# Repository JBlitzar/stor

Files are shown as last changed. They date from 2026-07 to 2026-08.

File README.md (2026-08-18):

# stor

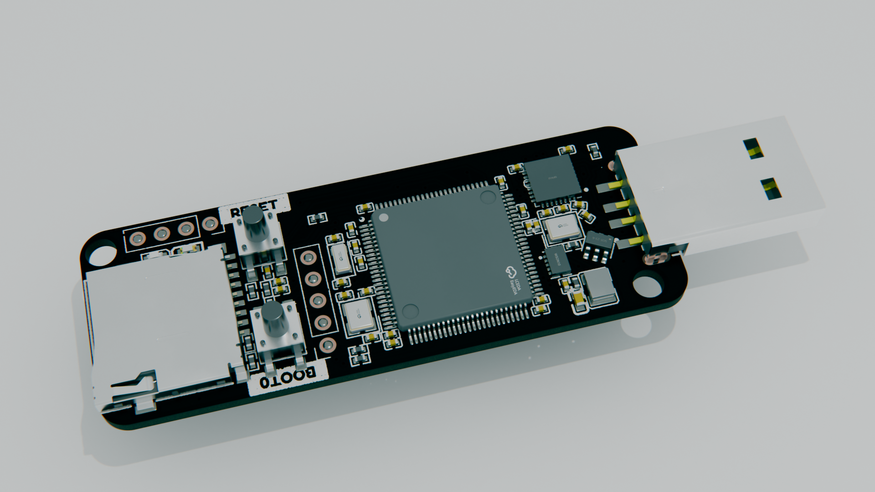
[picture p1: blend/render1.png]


A USB2.0 High Speed flash drive with a hotswappable MicroSD backend. 

The specs:

- USB 2.0 Hi-Speed
- STM32H723VGT6 MCU (Cortex-M7, 550 MHz class)
- MicroSDXC backend, up to 2 TB
- ~30–40 MB/s sustained, approximately saturating USB2.0

I made this because I always thought USB flash drives were pretty neat. So much storage! Easy file transfer! Ability to USB-boot! Making my own seemed like the perfect justification. Then, I saw that eMMC prices have in fact been inflated in accordance with the whole 2026 AI RAM shortage thing. You know what is still cheap per GB? microSD. You can absolutely get a respectable amount of storage (64gb, 128gb, 256gb) for just $10-20 if you source smartly. And microSDs have endless customization. They go up to 2TB. There exist industrially-rated ones with super high endurance. And, unlike BGA eMMC, they are hot-swappable.

The STM middleman is also fun because it means I can do all sorts of things, from custom USB descriptors to on-the-fly encryption or compression. The H7 even has crypto primitives, so it would be lightning fast! Implementation of this coming soon after the initial firmware is validated.

## Schematic

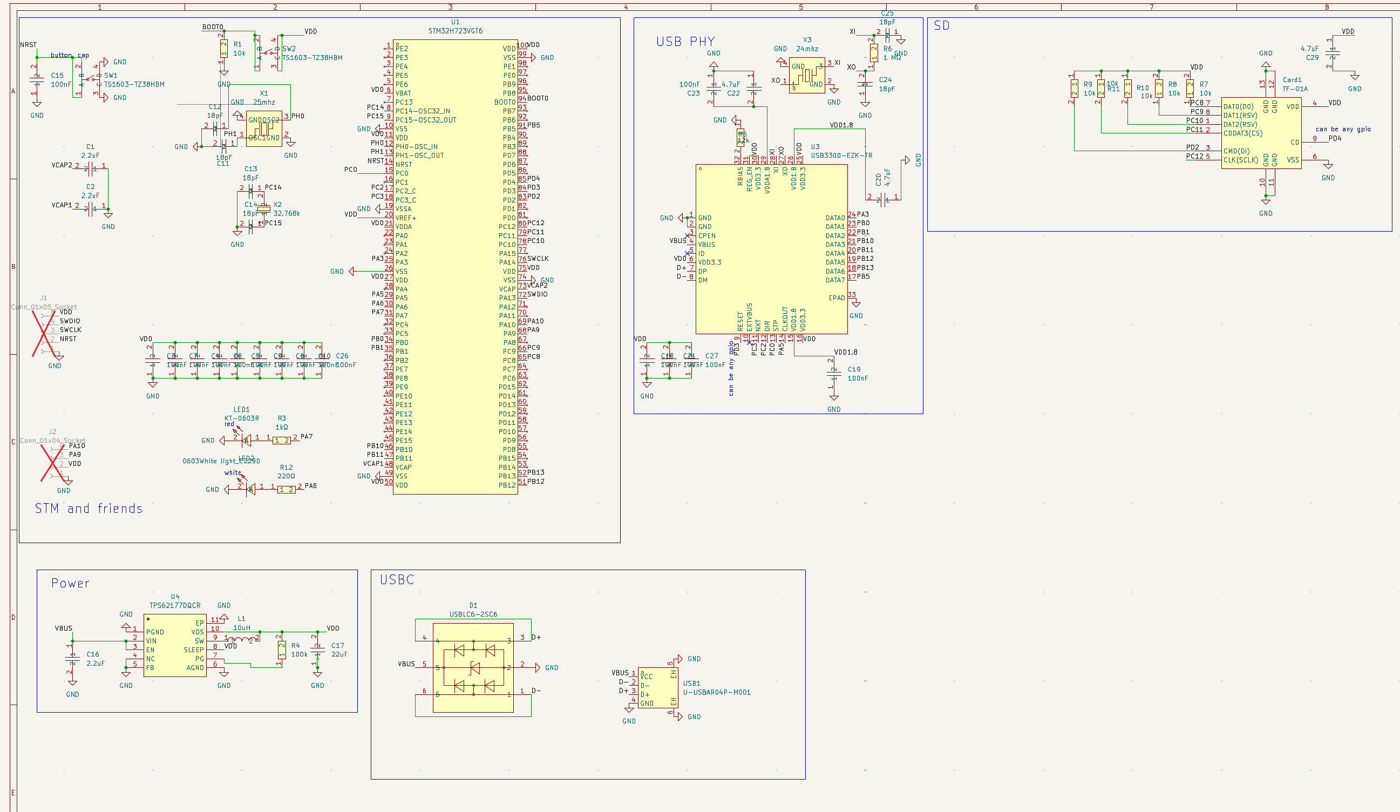
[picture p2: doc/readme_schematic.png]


## PCB

[Kicanvas](https://kicanvas.org/?repo=https%3A%2F%2Fgithub.com%2FJBlitzar%2Fstor%2Ftree%2Fmain%2FPCB%2Fstor)

F.cu and B.cu:

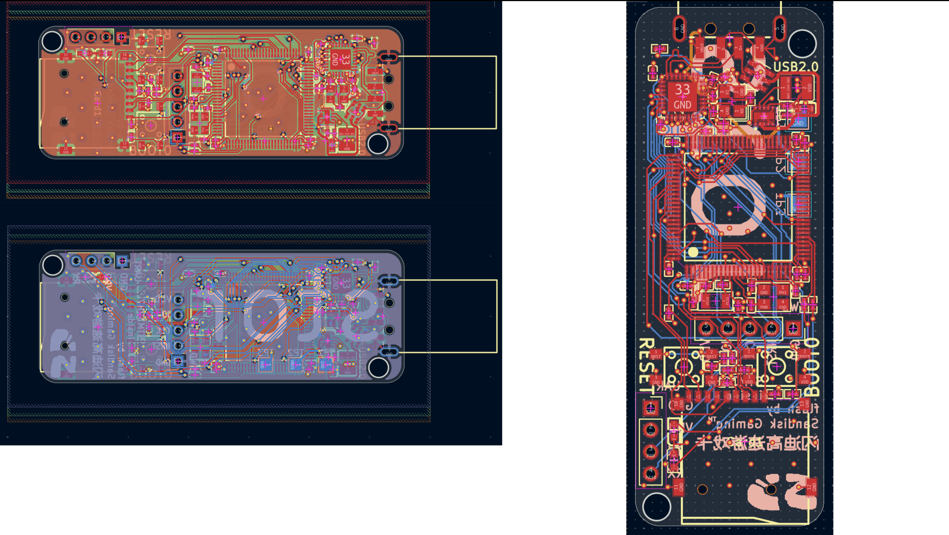
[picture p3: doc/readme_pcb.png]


## Usage

Standard USB to UART flashing configuration. Wiring diagram:

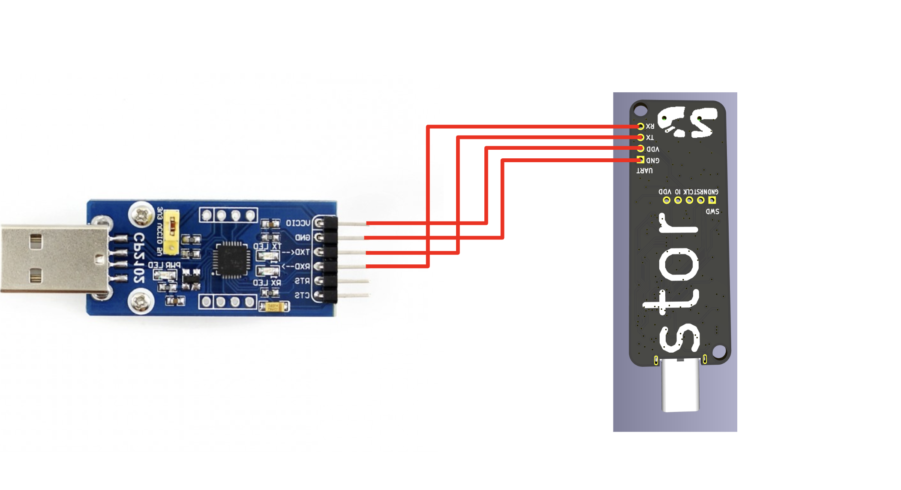
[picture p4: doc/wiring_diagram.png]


To flash the firmware:

1. `cd firmware`
2. Hold BOOT0, tap reset, release BOOT0
2. Run: `pio run -t upload`
3. Monitor: `pio device monitor`

It also might be possible to flash over USB. I haven't tested it though. Instructions are in [firmware/README.md](firmware/README.md), but in short:

1. `cd firmware`
2. `pio run` (to build)
3. Plug in the board, hold BOOT0, tap reset, release BOOT0
4. `dfu-util -a 0 -s 0x08000000:leave -D .pio/build/stor/firmware.bin`

I'll make this the default `pio run -t upload` behavior after it's been tested and verified.

Only plug in a microsd card after a successful first flash!

## CAD

Assembly STEP is at [cad/stor_assembly.step](cad/stor_assembly.step)

Case STEP is at [cad/stor_case.step](cad/stor_case.step)

Case is attached to the PCB through the circular pegs that go into the holes in the PCB

Onshape link: https://cad.onshape.com/documents/a7e5e47cc0cfc056916b5738/w/17c4e94553a6fc2d4495a917/e/2d8b03d1ea07a2cbf9c4bec4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

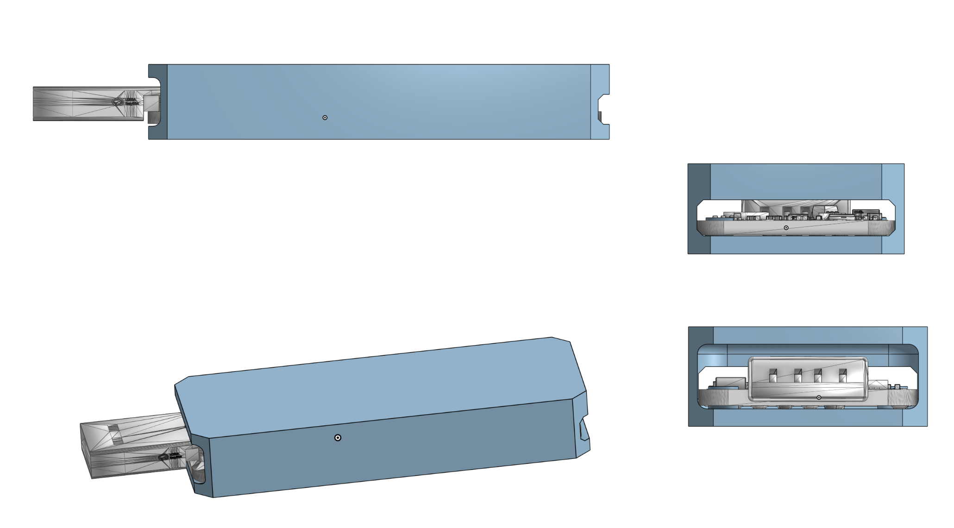
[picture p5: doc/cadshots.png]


## Credits

[TinyUSB](https://github.com/hathach/tinyusb) for the USB stack! LICENSE file is included in [firmware/lib/tinyusb](firmware/lib/tinyusb)

## BOM

|Item |Link |Cost |Notes |
|---|---|-----|---|
|CP2102 for flashing |http://waveshare.com/cp2102-usb-uart-board-type-a.htm|0 |Cost is zero because I'm flashing via FPGA. For others looking to reproduce, this is the simplest thing you can buy |
|SD card |https://www.lcsc.com/product-detail/C42416580.html |0 |I'll be paying out of pocket or self-sourcing. Feel free to gnab whatever listing you want, this is a 128gb listing for which I have no idea if it'll be reputable. Your safest bet is a sandisk off of amazon or digikey|
|PCB |N/A |7.1  |green pcb; other colors cost $5 more |
|PCBA |N/A |67.97|2x PCBA is the MOQ |
|JLC shipping + taxes|N/A |3.3  |Shipping special offer; may cost up to $8, but at the same time I have some coupons. So the total will work out about the same |
|Total |N/A |78.37| |
### Fabrication BOM

You'll find the rest of the fabrication outputs at [PCB/stor/production_real](PCB/stor/production_real)

|Designator |Footprint |Quantity|Value |LCSC Part #|
|---|---|---|---|---|
|C1, C16, C2 |C0402 |3 |2.2uF |C12530 |
|C10, C15, C18, C19, C21, C23, C26, C27, C3, C4, C5, C6, C7, C8, C9|C0402 |15 |100nF |C1525 |
|C11, C12, C13, C14, C24, C25|C0402 |6 |18pF |C1549 |
|C17 |C0603 |1 |22uF |C59461 |
|C20, C22, C29 |C0402 |3 |4.7uF |C23733 |
|CARD1 |TF-SMD_TF-01A |1 |TF-01A |C91145 |
|D1 |SOT-23-6_L2.9-W1.6-P0.95-LS2.8-BL |1 |USBLC6-2SC6 |C7519 |
|J1 |PinSocket_1x05_P2.54mm_Vertical |1 |Conn_01x05_Socket | |
|J2 |PinSocket_1x04_P2.54mm_Vertical |1 |Conn_01x04_Socket | |
|L1 |IND-SMD_L3.2-W2.5_CKST322512-2.2UH |1 |10uH |C39846661  |
|LED1 |LED-SMD_L1.6-W0.8-R-RD |1 |KT-0603R |C2286 |
|LED2 |LED0603-R-RD_WHITE |1 |0603White light_C2290 |C2290 |
|R1, R10, R11, R7, R8, R9|R0402 |6 |10k |C25744 |
|R12 |R0402 |1 |220Ω |C25091 |
|R3 |R0402 |1 |1kΩ |C11702 |
|R4 |R0402 |1 |100k |C25741 |
|R5 |R0402 |1 |12k |C25752 |
|R6 |R0402 |1 |1 MΩ |C26083 |
|SW1, SW2 |SW-SMD_4P-L4.5-W4.5-P3.00-LS6.8 |2 |TS1603-TZ38HBM |C36938886  |
|U1 |LQFP-100_L14.0-W14.0-P0.50-LS16.0-BL |1 |STM32H723VGT6 |C730142 |
|U3 |QFN-32_L5.0-W5.0-P0.50-BL-EP3.4 |1 |USB3300-EZK-TR |C108383 |
|U4 |WSON-10_L3.0-W2.0-P0.50-BL-EP |1 |TPS62177DQCR |C91241 |
|USB1 |USB-SMD_KH-USB-AM-4P-CB |1 |U-USBAR04P-M001 |C386752 |
|X1 |CRYSTAL-SMD_4P-L3.2-W2.5-BL |1 |25mhz |C9006 |
|X2 |OSC-SMD_L3.2-W1.5 |1 |32.768k |C97606 |
|X3 |CRYSTAL-SMD_4P-L3.2-W2.5-BL |1 |24mhz |C7420736 |

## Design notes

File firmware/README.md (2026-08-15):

# stor firmware

TinyUSB + ST HAL firmware. It's mostly boilerplate and plumbing.

## Build

```sh
pio run
```

## Flash

Either obtain a CP2102 dongle, or follow the instructions in [`fpga`](fpga/).

Hold BOOT0, tap reset, release
BOOT0, then:

```sh
pio run -t upload
```

### Flash over USB (untested)

Plug the board, then the
same BOOT0 sequence, then:

```sh
dfu-util -a 0 -s 0x08000000:leave -D .pio/build/stor/firmware.bin
```

This will probably work, but it's not tested. be prepared to potentially flash over uart/swd.

I'll make this the default `pio run -t upload` behavior after it's been tested and verified.

## Console

USART1 on PA9 (TX) / PA10 (RX), 115200 8N1, 3.3 V.

```sh
pio device monitor
```

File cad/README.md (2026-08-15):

Onshape link's at https://cad.onshape.com/documents/a7e5e47cc0cfc056916b5738/w/17c4e94553a6fc2d4495a917/e/2d8b03d1ea07a2cbf9c4bec4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

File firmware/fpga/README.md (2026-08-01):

# Icepi Zero FPGA flasher

This is how I'm going to personally flash since I want to avoid spending 16 dollars. 

You only need this if you happen to have an Icepi Zero lying around. For
everyone else, a CP2102 dongle is simpler.

## How it works

[`top.sv`](top.sv) is a pure combinational pass-through. esptool talks to the
Icepi's onboard FTDI exactly as it would to a CP2102; the FPGA just forwards
the data and modem-control lines (RTS->EN, DTR->boot) to four GPIOs:

| FTDI signal | FPGA pass-through | Hairtag pin |
|---|---|---|
| TXD (`usb_rx`) | `flash_txd` | TXD (ESP U0RXD) |
| RXD (`usb_tx`) | `flash_rxd` | RXD (ESP U0TXD) |
| RTS# (`usb_rtsn`)| `flash_en`  | EN (CHIP_EN) |
| DTR# (`usb_dtrn`)| `flash_dtr` | DTR (GPIO9 boot)|

## Wiring

The four signal GPIOs sit on the odd-numbered outer row, so VCC/GND/signals
are all reachable along one side of the 40-pin header:

| stor pin | Icepi 40-pin header | ECP5 site |
|---|---|---|
| VCC | pin 1 (VDD) | — (rail) |
| GND | pin 9 (GND) | — (rail) |
| TXD | pin 3  | T2 |
| RXD | pin 5  | R2 |



## Build and load

Requires the open-source ECP5 toolchain (`yosys`, `nextpnr-ecp5`, `ecppack`,
`openFPGALoader`).

```bash
make debug    # load to SRAM (lost on power cycle) - good for flashing sessions
make install  # write to flash (persists)
make clean
```

Once the bitstream is loaded, flash the normal way.

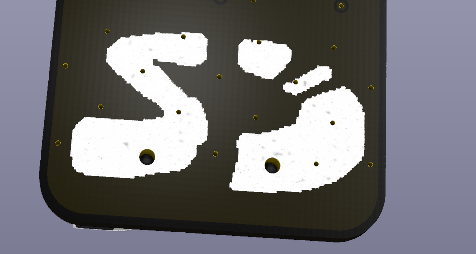
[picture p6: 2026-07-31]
doc/h.png

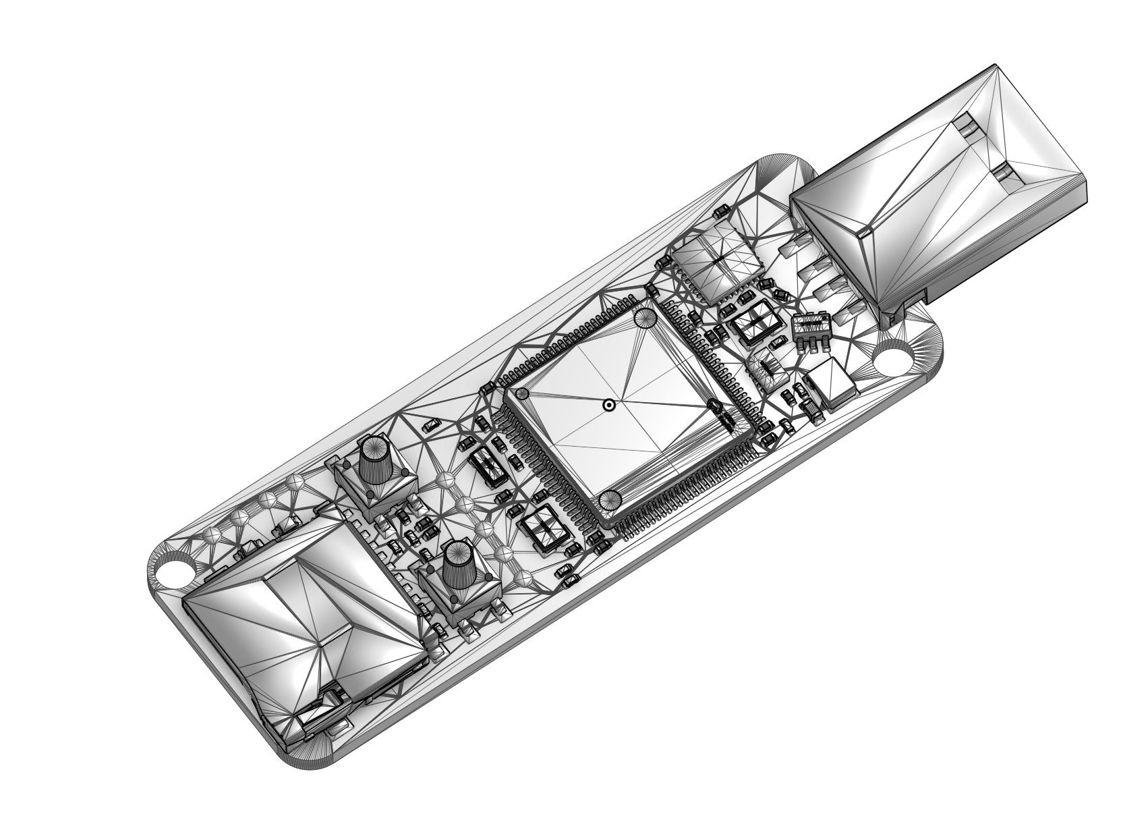
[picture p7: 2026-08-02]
doc/cadshot.png

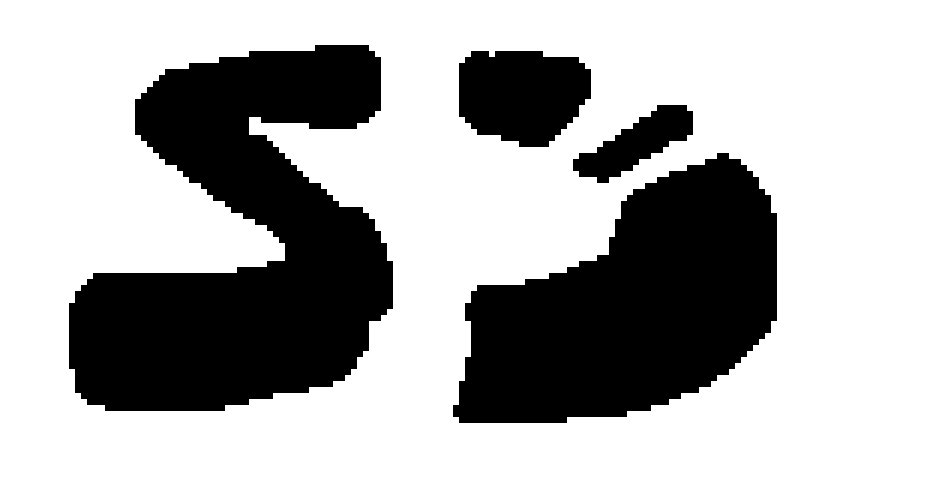
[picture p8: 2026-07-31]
doc/sd.png

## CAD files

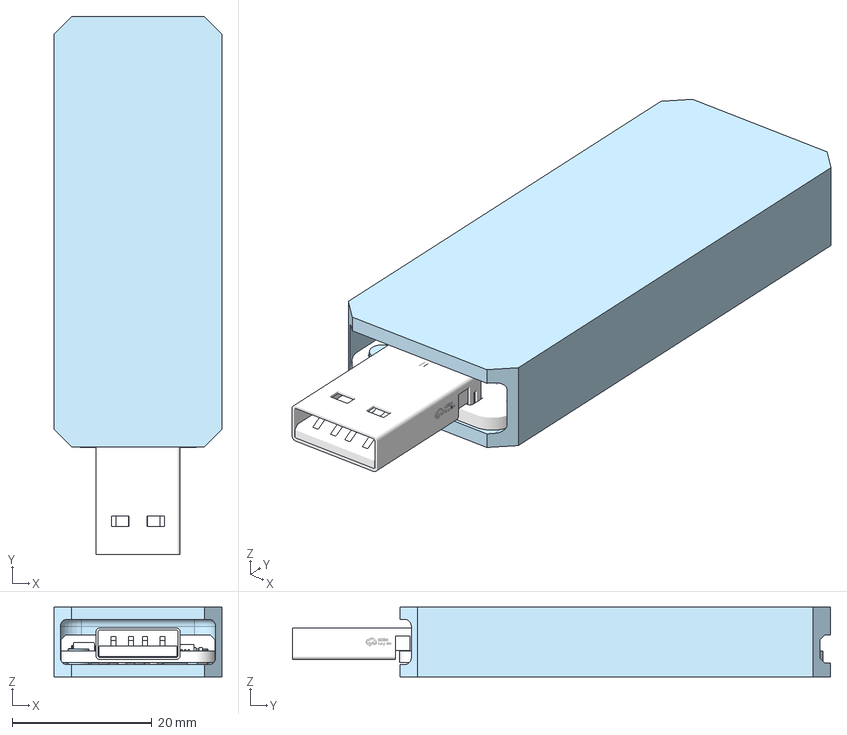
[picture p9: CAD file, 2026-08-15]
cad/stor_assembly.step
24.0 x 76.9 x 10.0 mm
SOLDER_25mhz_X1_35_3 x 8
SOLDER_4_7uF_C29_26_1 x 54
SOLDER_USB3300_EZK_TR_U3_52_7 x 16
SOLDER_STM32H723VGT6_U1_19_99 x 50
R0402_L1.0-W0.5-H0.4 (14) x 11
C0402_L1.0-W0.5-H0.5 x 27
SOLDER_STM32H723VGT6_U1_19_9 x 50
SOLDER_TS1603_TZ38HBM_SW2_39_3 x 8
SOLDER_TPS62177DQCR_U4_28_9 x 10
SOLDER_Conn_01x05_Socket_J1_33_4 x 7
QFN-32_L5.0-W5.0-H0.9-P0.50 (17)
SOT-23-6_L2.9-W1.6-H1.5-LS2.8-P0.95 (4)
SOLDER_USB3300_EZK_TR_U3_52_9 x 16
QFN-32_L5.0-W5.0-H0.9-P0.50 (15)
QFN-32_L5.0-W5.0-H0.9-P0.50 (7)
QFN-32_L5.0-W5.0-H0.9-P0.50 (6)
USB-SMD_KH-USB-AM-4P-CB
QFN-32_L5.0-W5.0-H0.9-P0.50 (32)
QFN-32_L5.0-W5.0-H0.9-P0.50 (3)
SOLDER_TF_01A_Card1_8_9 x 9
SOLDER_U_USBAR04P_M001_USB1_23_1 x 2
LED0603-R-RD_WHITE (1)
SOLDER_220?_R12_4_1 x 22
SOLDER_U_USBAR04P_M001_USB1_23_5 x 4
SOT-23-6_L2.9-W1.6-H1.5-LS2.8-P0.95 (6)
SOLDER_USBLC6_2SC6_D1_16_5 x 6
SOLDER_TF_01A_Card1_8_13 x 2
QFN-32_L5.0-W5.0-H0.9-P0.50 (29)
SOLDER_TPS62177DQCR_U4_28_10
SOLDER_TF_01A_Card1_8_14 x 2
SOLDER_KT_0603R_LED1_25_1 x 4
QFN-32_L5.0-W5.0-H0.9-P0.50 (24)
USB-SMD_KH-USB-AM-4P-CB (3)
USB-SMD_KH-USB-AM-4P-CB (8)
QFN-32_L5.0-W5.0-H0.9-P0.50 (11)
QFN-32_L5.0-W5.0-H0.9-P0.50 (9)
LED0603-R-RD_WHITE
LED0603_L1.6-W0.8-H0.6 (1)
QFN-32_L5.0-W5.0-H0.9-P0.50 (1)
QFN-32_L5.0-W5.0-H0.9-P0.50 (18)
SOLDER_32_768k_X2_5_1 x 2
LED0603_L1.6-W0.8-H0.6 (2)
QFN-32_L5.0-W5.0-H0.9-P0.50 (12)
QFN-32_L5.0-W5.0-H0.9-P0.50 (25)
LED0603-R-RD_WHITE (3)
QFN-32_L5.0-W5.0-H0.9-P0.50 (19)
QFN-32_L5.0-W5.0-H0.9-P0.50 (27)
LED0603_L1.6-W0.8-H0.6 (3)
SOT-23-6_L2.9-W1.6-H1.5-LS2.8-P0.95 (3)
SOT-23-6_L2.9-W1.6-H1.5-LS2.8-P0.95 (2)
SOLDER_22uF_C17_21_1 x 2
QFN-32_L5.0-W5.0-H0.9-P0.50 (26)
C0603_L1.6-W0.8-H0.8
QFN-32_L5.0-W5.0-H0.9-P0.50 (22)
QFN-32_L5.0-W5.0-H0.9-P0.50 (5)
QFN-32_L5.0-W5.0-H0.9-P0.50 (30)
QFN-32_L5.0-W5.0-H0.9-P0.50 (21)
CRYSTAL-SMD_4P-L3.2-W2.5-BL.001 x 2
USB-SMD_KH-USB-AM-4P-CB (7)
WSON-10_L3.0-W2.0-H0.8-P0.50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

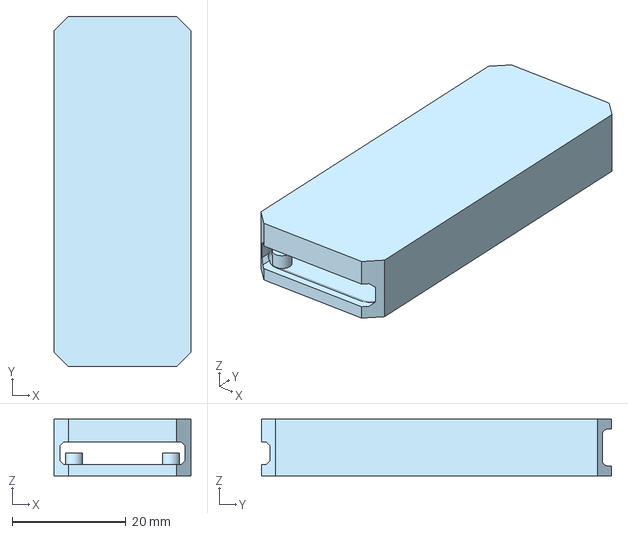
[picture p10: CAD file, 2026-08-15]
cad/stor_case.step
24.0 x 61.5 x 10.0 mm

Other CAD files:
blend/stor.blend

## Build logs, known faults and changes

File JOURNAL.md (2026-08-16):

---
title: "USB-C MicroSD Flash Drive"
author: "JBlitzar"
description: "High-speed USB-C microSD flash drive"
created_at: "2026-07-28"
---

# July 28: Developed the flash drive concept

Basically came up with the idea and assessed feasability. After thinking about my previous hardware projects, I thought a flash drive would be super cool. Why?

 - I love USB. Doing HS would still be USB but would be slightly levelled-up. usb3.0 in general like requires like NDA or FPGA or custom ASIC, so I thought I would go one step up instead of two for now.
 - I realized that eMMC is super expensive these days! shoutout to the [2025–present global memory supply shortage](https://en.wikipedia.org/wiki/2025%E2%80%93present_global_memory_supply_shortage)
, I guess. Sort of affects all memory-related ICs. It's not as bad as $80 for 2GB of LPDDR4 chip ram though. Still, decently expensive. I decided for this project I wanted to actually store files of a meaningful size.
 - The solution? [MicroSD cards](https://xkcd.com/691/)!! They have great data density (the highest-end ones can store up to 2TB these days), and are pretty cheap, especially if you source them off of the OEM supply chain like LCSC rather than consumer marketplaces like Amazon. I found a deal for 128GB for just $10 (??! probably trash data durability or a scam or both, but anyways I found plenty of other cheap listings that aren't too-good-to-be-true cheap). Plus, hotswappable storage is very hacker aesthetic. 
 - The good news is that USB3.0 isn't even worth chasing anymore, since we'll be able to saturate the SD card link speed itself. The link speeds actually don't bottleneck each other too much either way. With UHS-I enabled microSDs we're looking at 50 megabytes per second, and maybe 30-40 without. Pretty good.

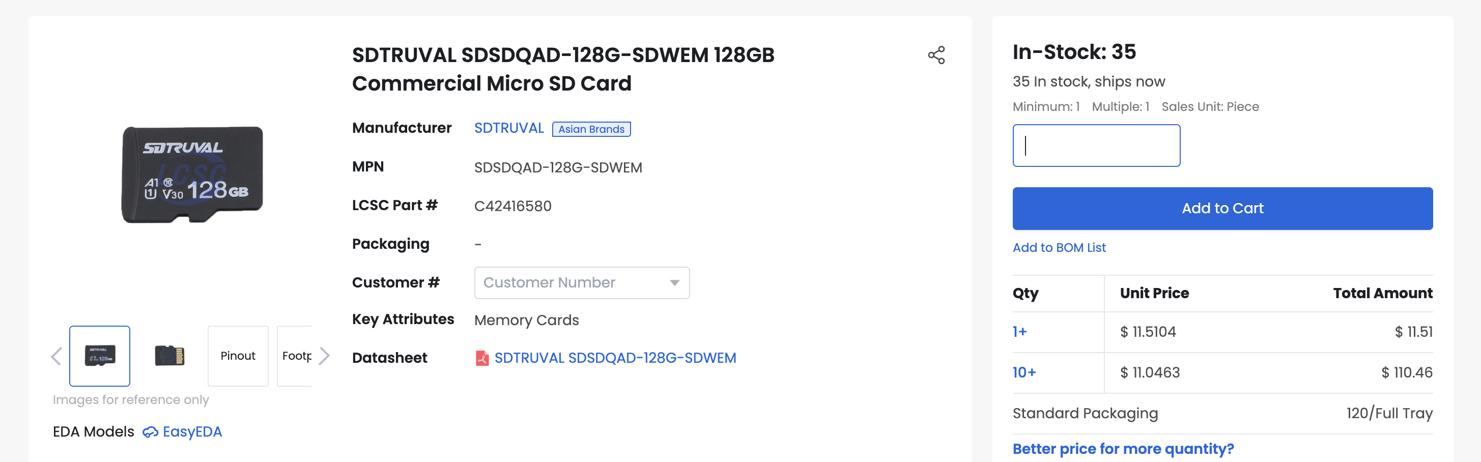
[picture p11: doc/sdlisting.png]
 

 yeah uh otherwise not much more to show, just research and concept

Time spent: 0.5 hours

# July 29: Selected the microcontroller and USB PHY

Did some research, locked in some more precise specs. 

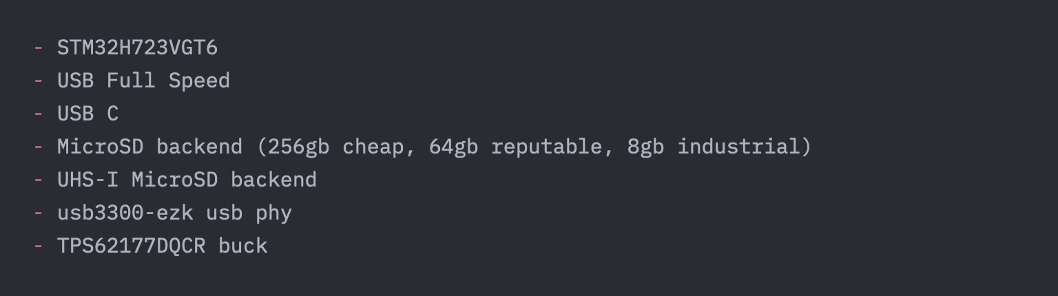
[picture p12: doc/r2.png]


Time spent: 0.5 hours

# July 29: Researched and completed the schematic

STM chip is the chip for the job. So unfortuantely I will have to depart from my goat espressif for this project. There do exist STM chips that have built in USB2.0 HS PHY, but they are more expensive (the lcsc listing I found was low stock AND $28 per, which is crazy considering the rk3566 costs just $14).

In the end, STM32H723VGT6 plus usb3300 usb phy is the way to go. The STM *does* have built-in sd card phy which is nice, and the clock speed is more than enough to saturate USB2.0 link speed. Later, I could do something cool, like on-the-fly encryption or something

Time elapsed taken from gh commit timestamps, I was working pretty much continuously.

Had to find actual resources. The STM datasheet wasn't too helpful, and the [DISCO schematic](st.com/resource/en/schematic_pack/mb1248-h747i-d03-schematic.pdf
) was... pretty intimidating, because it has examples for *every* peripheral. I went off of a [reddit post](https://www.reddit.com/r/PCB/comments/1n8w67u/stm32h723vet6_breakout_board_feedback_advice_for/
) for hardware/strapping, and hopefully I can just expose some GPIOs, flash over SWD, and pray.

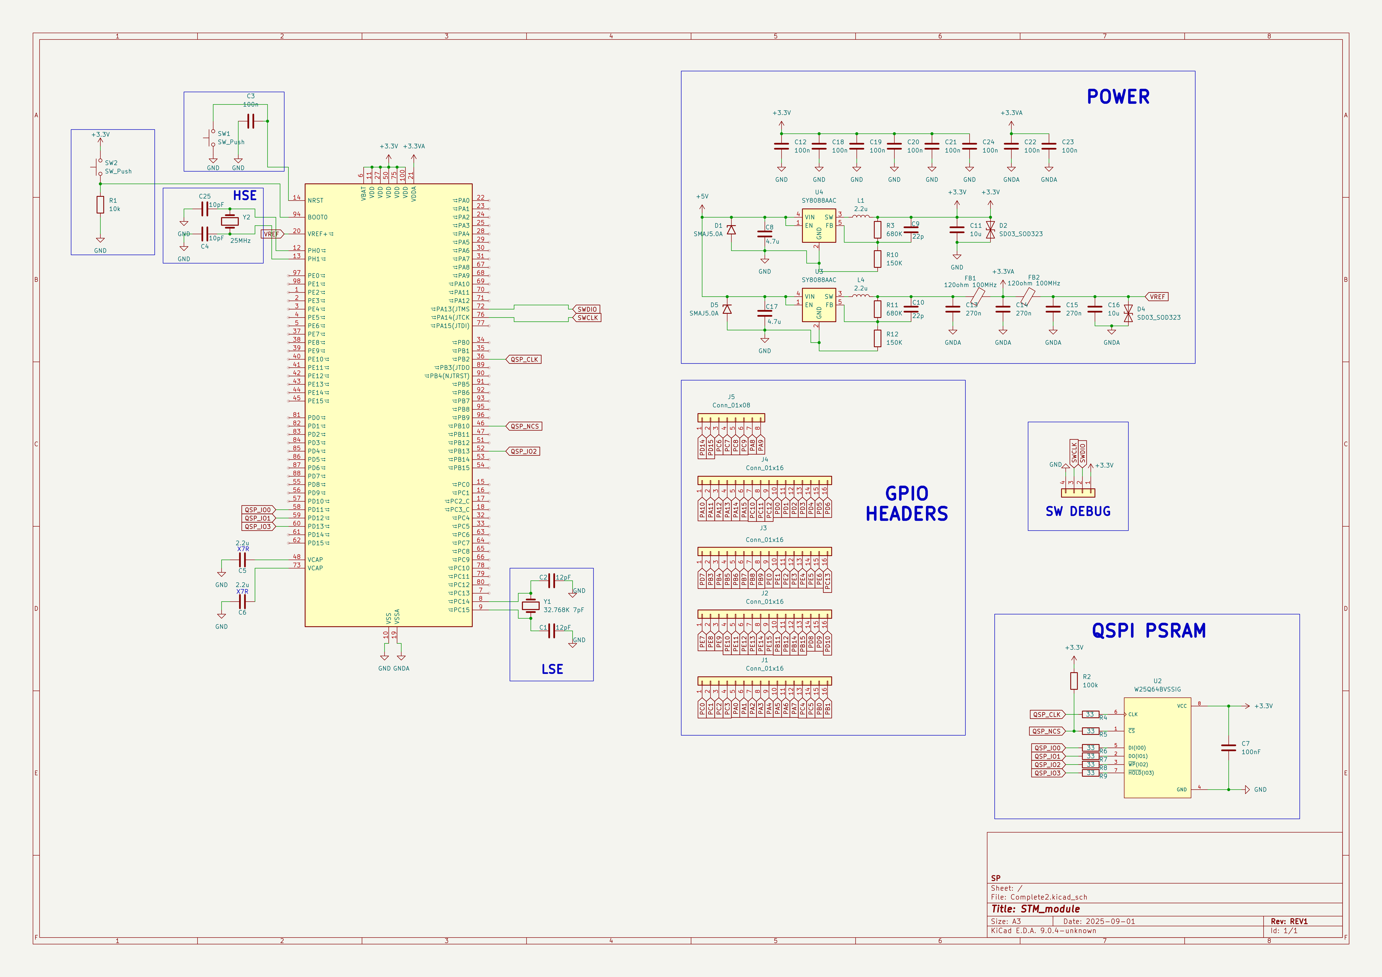
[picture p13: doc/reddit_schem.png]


Then I just researched which pins to connect up for the sd card and found a proper example schematic for the USB PHY (although they put ferrite beads everywhere which I omitted).

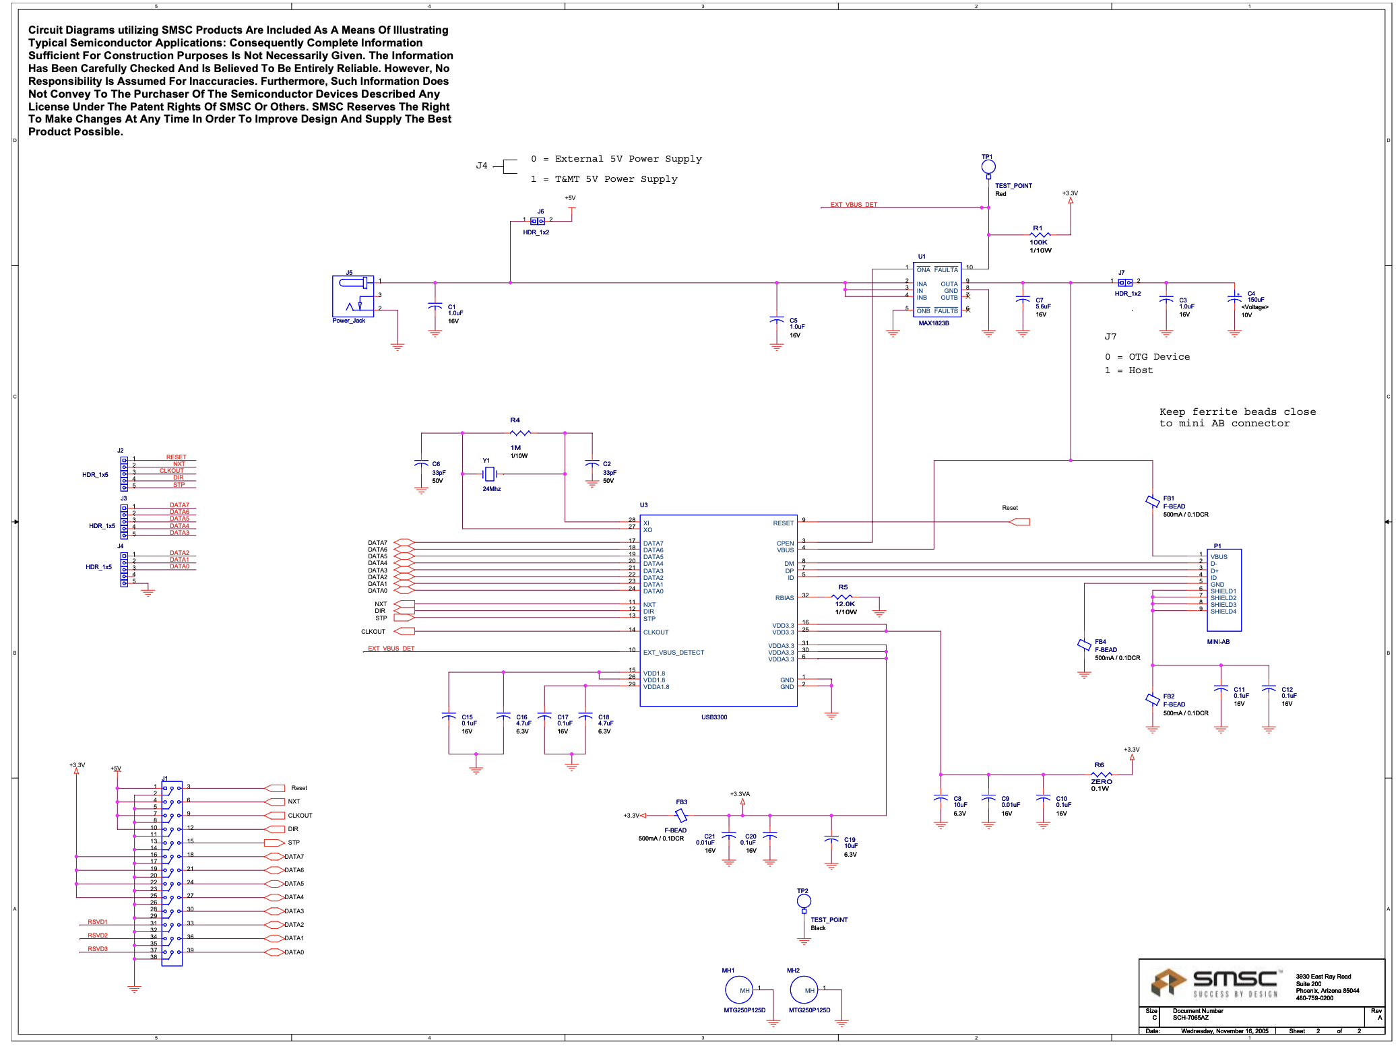
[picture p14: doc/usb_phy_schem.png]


TPS62177DQCR had a perfectly acceptable example schematic

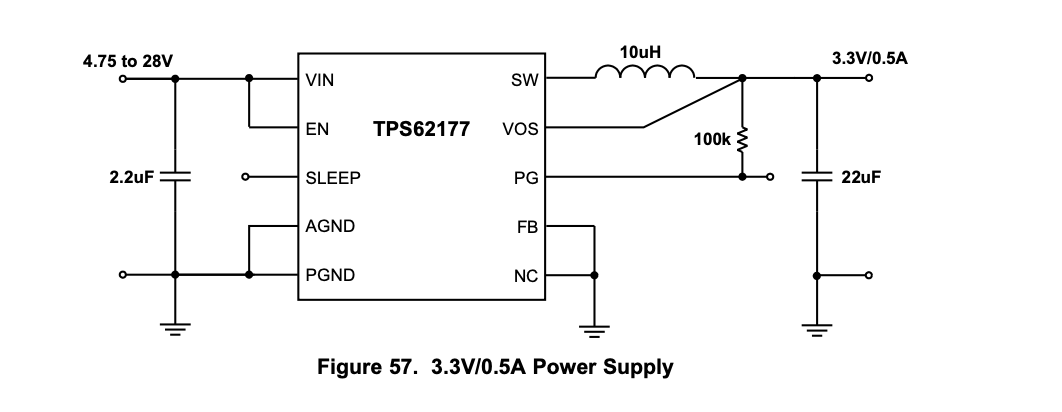
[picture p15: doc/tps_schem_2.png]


Then I put it all together! Had to use an A3 sheet because so big lol 

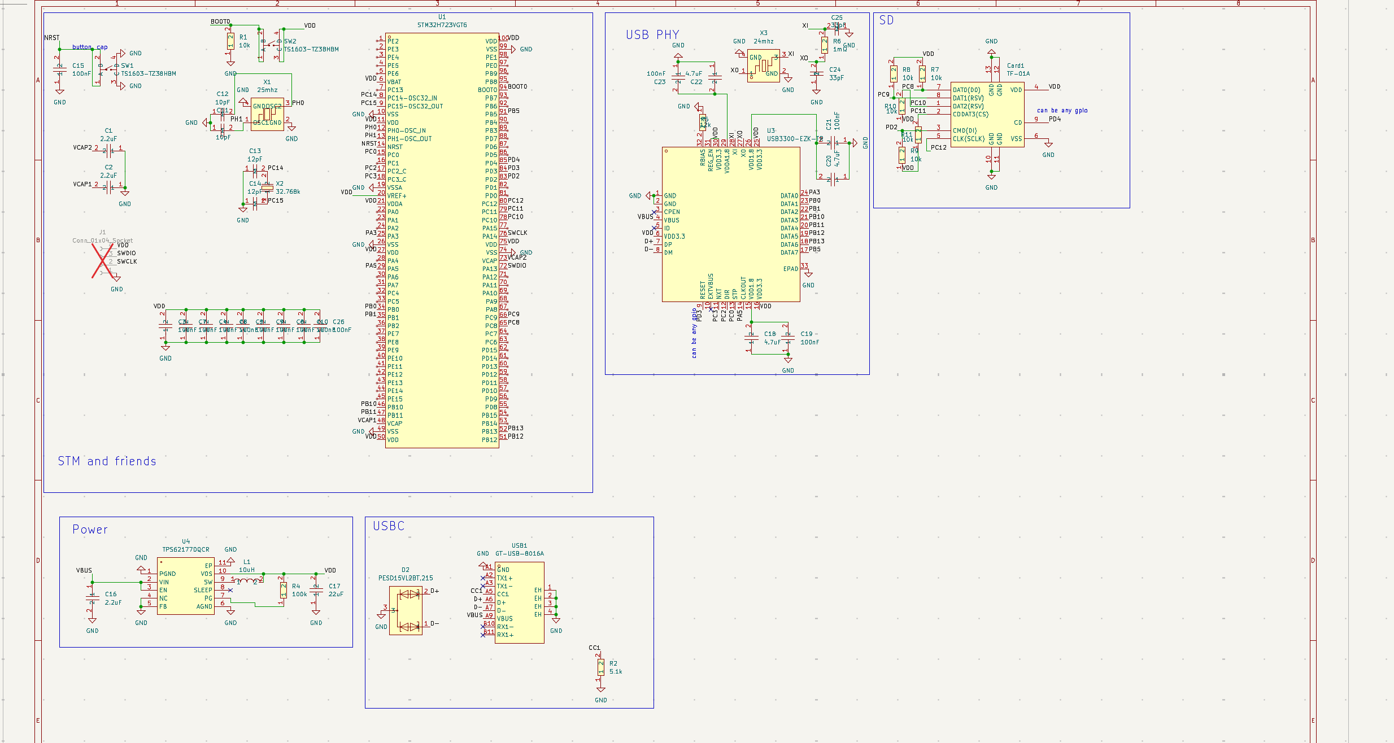
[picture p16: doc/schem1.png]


The STM pins were unfortunately not... charitably labelled. I used a lot of cmd+f.

Also some confusion between VDD/VDDA and GND/GNDA. Since I'm not doing any analog stuff, I merged them. Basically, the reddit PSU situation was way overengineered. That's why I went with the TPS.

So I guess research and schematic both took a surprising amount of time here.

Time spent: 4 hours

# July 29: Placed and routed the PCB

Placement and routing !!

You know what they say, good placement is 90% of good routing. What's cool is that I was pretty much able to fit everything in a standard thumb-drive footprint. Well, a slightly chunky thumb drive. Thumb drives are usually 18x60mm ish with casing, mine stands at 20mm wide without casing. Still acceptable. 

this is my first four-layer PCB, although honestly it feels like a two-layer pcb because I'm trying to keep the gnd and power planes solid, so there are really only two signal planes, just like normal. For the two most common traces though, gnd and vcc, all you have to do is via down and you tap the plane. GND plane important for usb2.0 diff pair, and four-layer esp important because it means the layers are thinner so impedance matching works out.

I'm not here to talk about impedance matching though, I just did placement. Here are some progress pics:

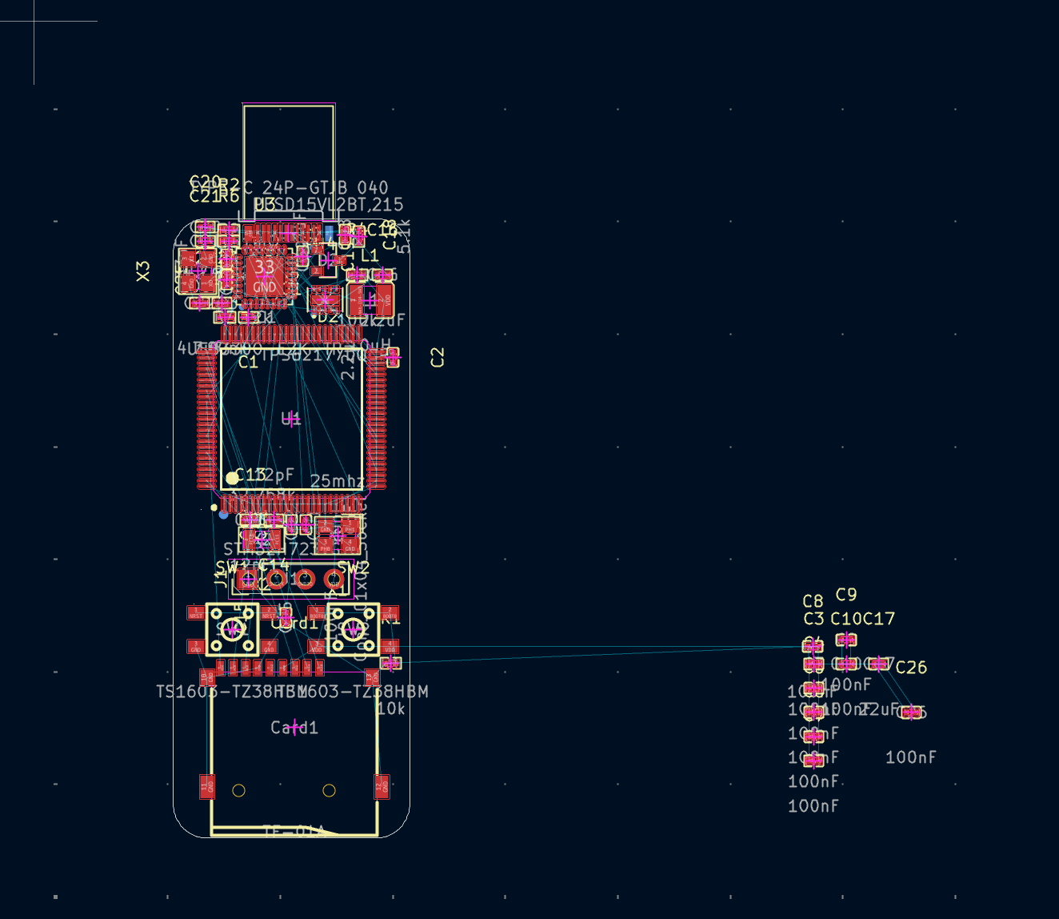
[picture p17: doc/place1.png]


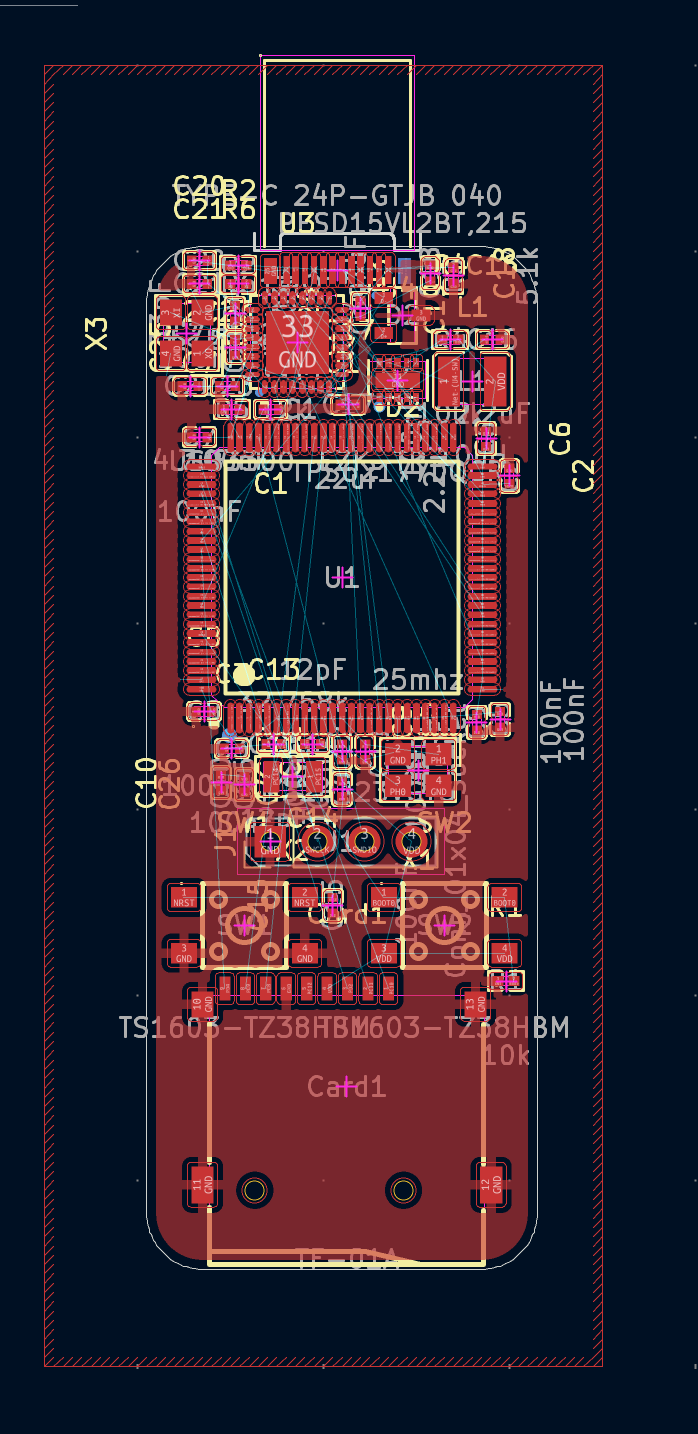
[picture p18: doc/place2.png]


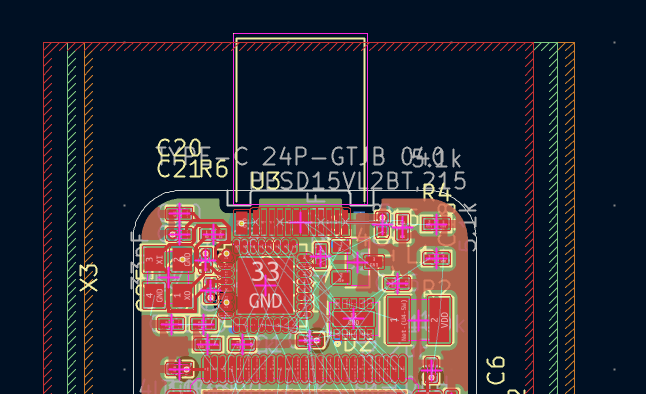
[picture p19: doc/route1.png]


Then I realized I had been putting off the differential pair when I really should have done it first. And really, my whole placement in that upper section was no good because of the rotation. I ended up completely refactoring the routing by changing the placement of the USB PHY ic. Which mean that the XO/XI caps plus the crystal had to all be re-placed.

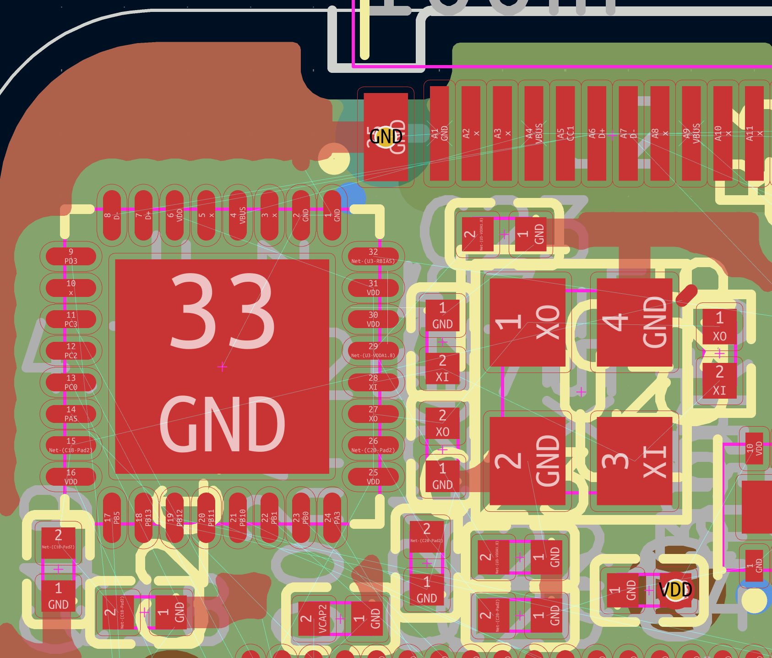
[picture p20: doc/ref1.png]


Then I just did the routing for the USB PHY and the sd card. Which is like sixteen bus lines, all interwoven.

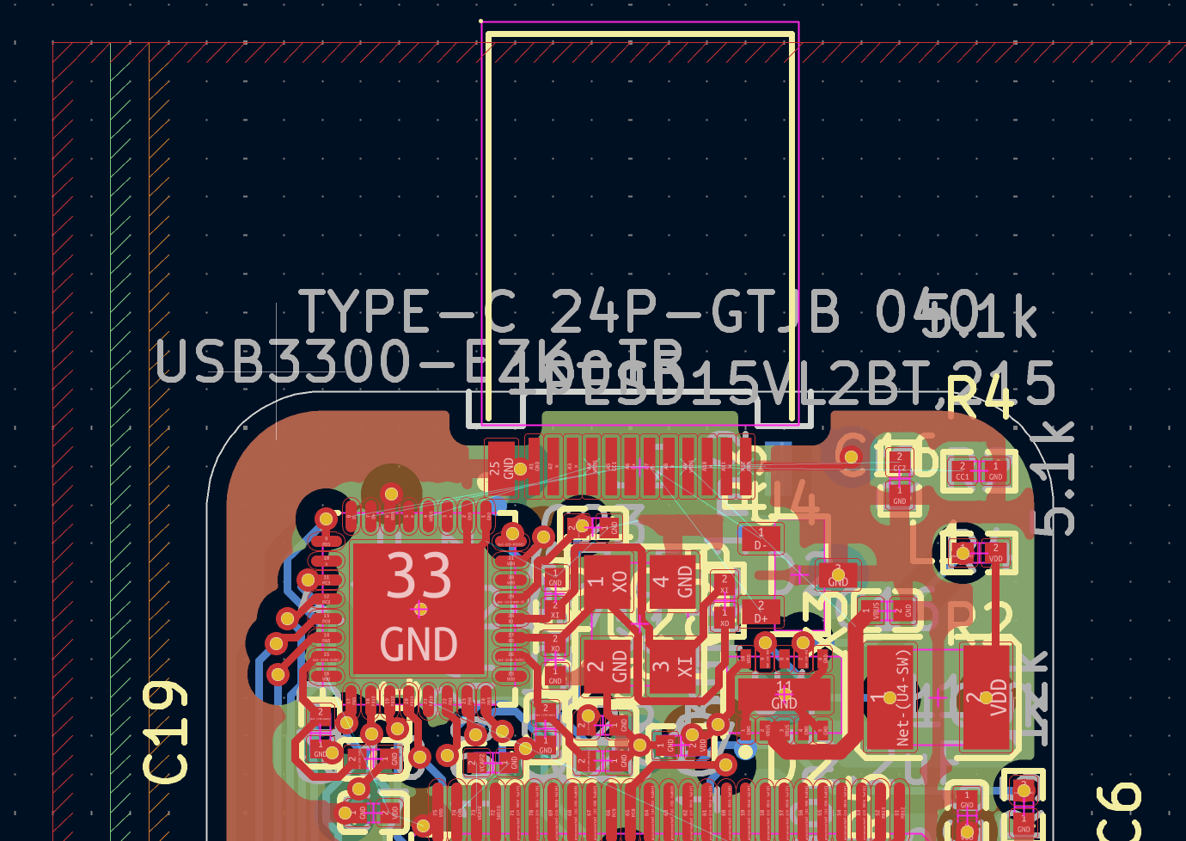
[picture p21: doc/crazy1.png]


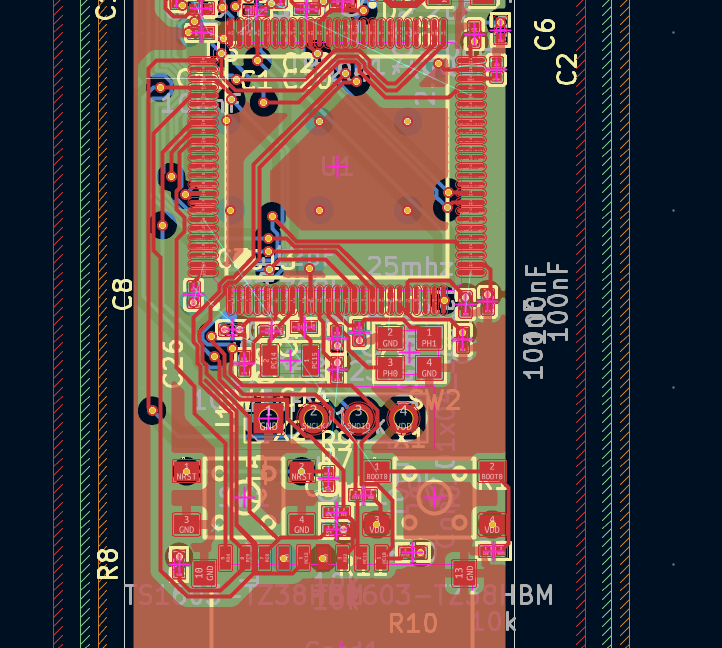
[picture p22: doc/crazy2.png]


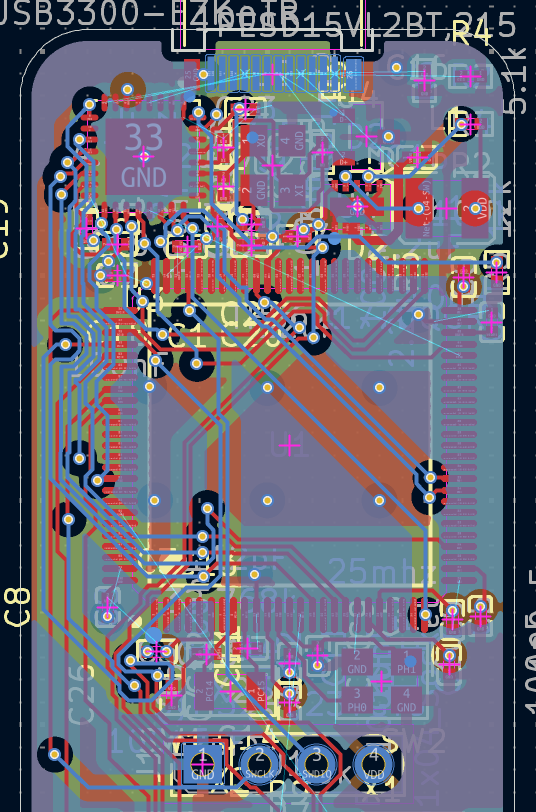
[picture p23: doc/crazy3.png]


Time spent: 2.5 hours

# July 30: Refined the routing and USB-C connector

Fussed with the routing a little bit. Managed to get some of the SD bus traces slightly further from the edge, which is probably good for case considerations even if solder mask exists. push and shove routing really is my goat. EasyEDA could never compete. (speaking of which, the newest kicad nightly update releases constraint-driven geometry! so cool! But I digress.)

Yeah, the routing looks quite... intricate ATP

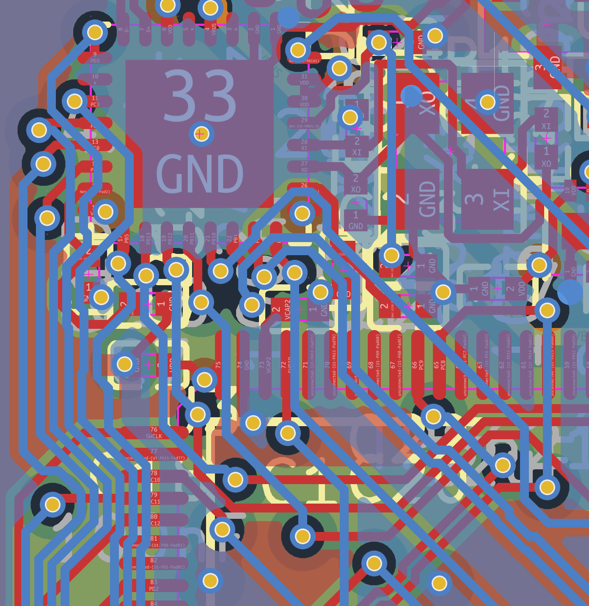
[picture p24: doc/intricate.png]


I also swapped out my THT USBC male for a different one that's less sketch and not weird and double-sided. This one will be more secure. It also had the escape routing I needed for the D+ and D- diff pairs to line up on the right side. 

Time spent: 1.0 hours

# July 31: Documented the design and added mounting holes

I realized that I hadn't been writing journals, so I wrote journals.

oh also I realized I haven't shown a 3d render, here it is!

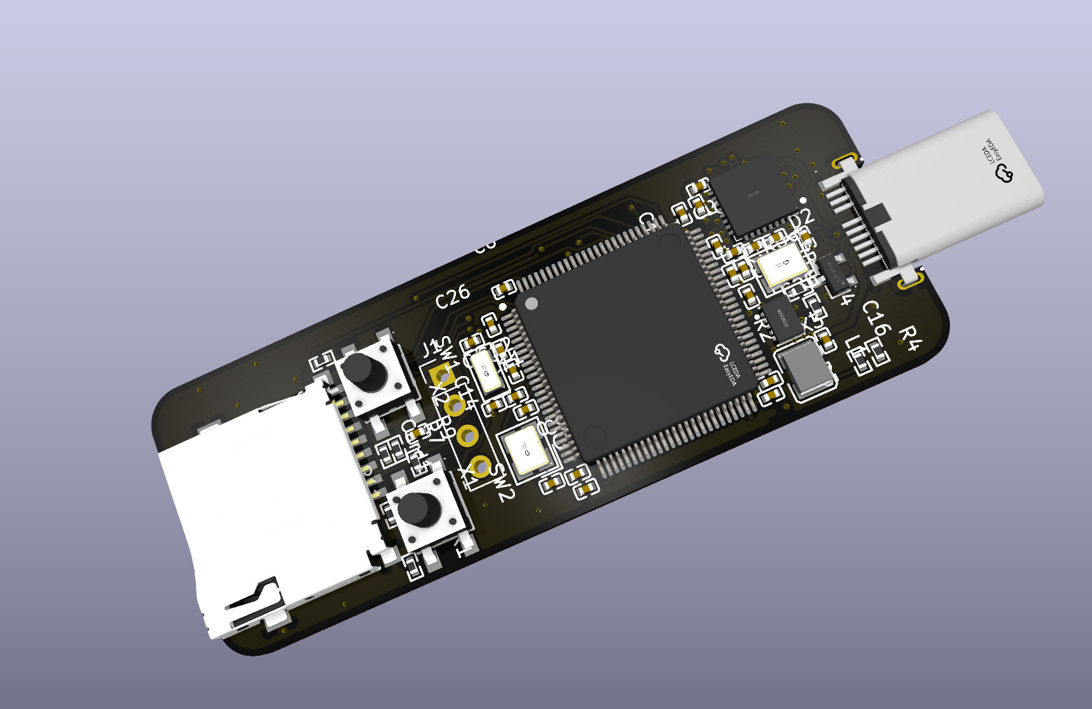
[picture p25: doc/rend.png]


The front is pretty packed with components. I think it looks cool.

I also uh drew my own SD logo in jspaint because I thought it'd be funny. I didn't pay the $1500 SD™ licensing fee. Front was pretty busy though so I guess it could only go on the back. It's a bit weird for that to be the only thing on the back, so I guess I have a few options:

- remove it
- add other (serious) silkscreen art
- add other spoof regulatory markings lol (FCC, CE, ROHS)

Anyways this was mostly just a whimsical thing I did.

I also added mounting holes!! had to shift the microsd holder a bit to the right and redo those traces but otherwise yeah. They are m3 holes. 

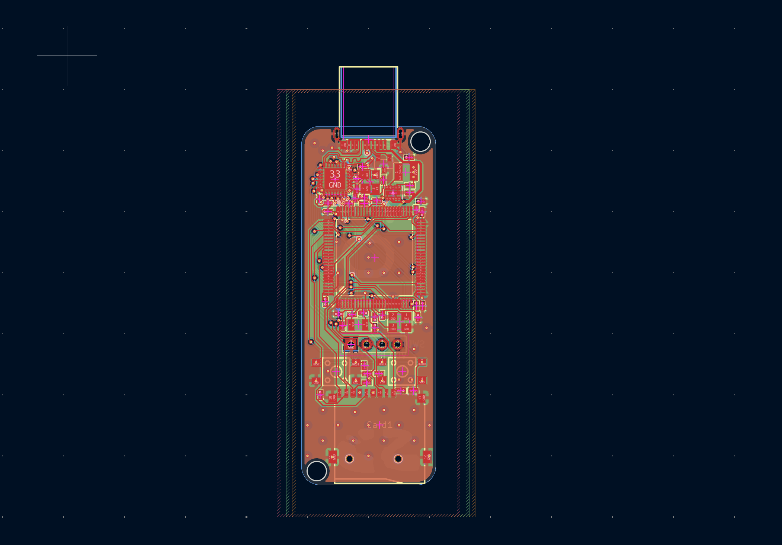
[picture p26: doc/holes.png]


TODOs:

- double check the premise of the schematic more closely (You shouldn't always trust reddit with these things. Last time I compared a hackaday tutorial to the datasheet on other stuff, it deviated in some really meaningful ways)
- Write firmware (non-trivial!)
- Get a quote + BOM optimize
- Docs, good README, flashing instructions
- potentially a beauty render

Time spent: 1.0 hours

# August 1: Routing hell

I posted my routing images around because I thought they looked cool, but I actually got free feedback!

Eliminated via-in-pad, re-matched my crystal caps, added some decoupling/bypass, and connected some pins that I needed to that I forgot 💀. Also used a different esd diode. 

I tried to be extra generous because apparently easyeda2kicad scams you and gives you bad courtyards. In eliminating via-in-pad, I finally bit the bullet and put some drunk components. 

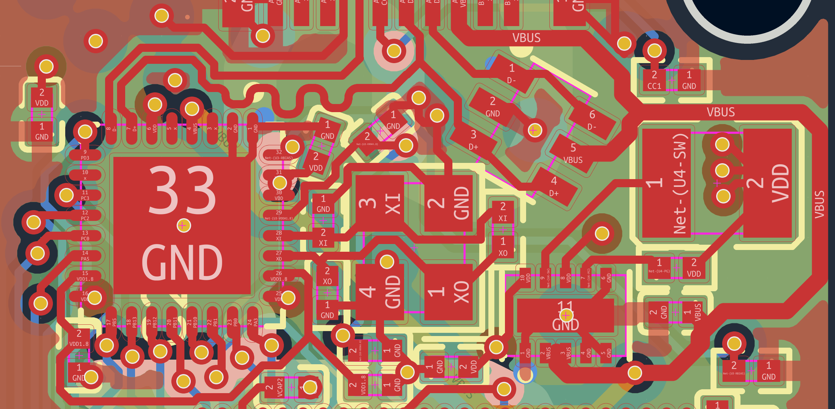
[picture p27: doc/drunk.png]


Time spent: 2.0 hours

# August 1: Firmware

Used TinyUSB. I'll be honest, I used a bit of AI. Mostly firmware is uninteresting here, some config knobs to change but mostly this is piping vendored tinyusb to vendored HAL_SD.

Also added a red LED and a white LED! Fun stuff. 

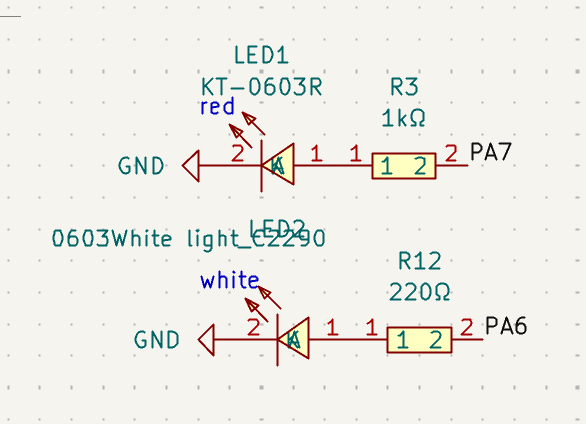
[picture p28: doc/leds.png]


The PR was comically large because of vendored TinyUSB being included (had to edit library.json), it's actually about 500 SLOC, and, like I said, it's mostly config / plumbing.

oh also because kicad was edited, and S-expressions take up many lines.

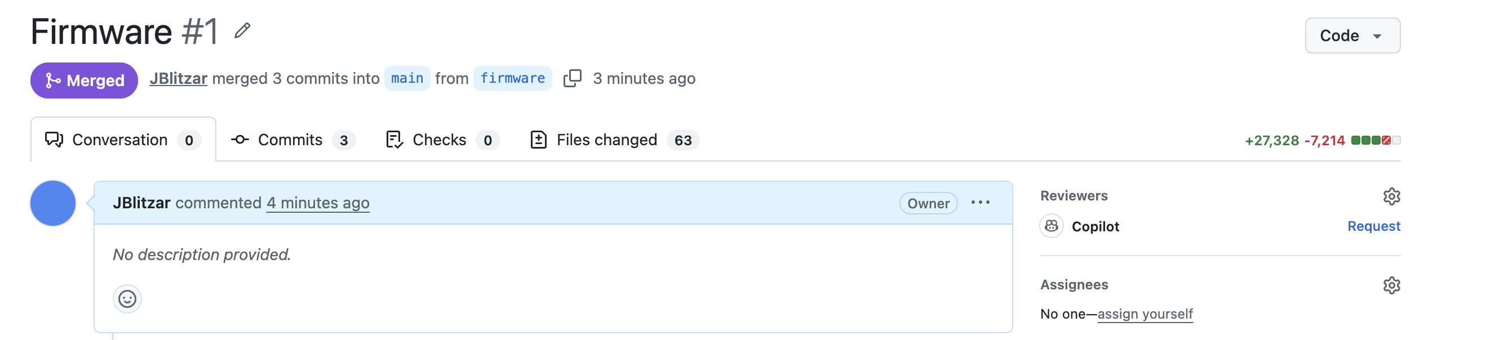
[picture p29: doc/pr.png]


Also dropped in my FPGA flashing docs. 

TODOs:

- Get a quote + BOM optimize
- Docs, good README, flashing instructions in README
- potentially a beauty render

Time spent: 1.0 hours

# August 2: bom opt

Got an initial quote coming in at $97... yikes. Absolutely optimizable. Mostly extended things that shouldn't need to be.

Two more blockers that are even more real though:
 - The usb connector I chose was standard-only. After digging on the JLC parts library, I found the holy grail: C3001294. In stock, usb2.0, economic, type-c, male, right-angle mount.
- X1 "the processing of this component is difficult. After placing an order, it will be reviewed. If PCBA advanced option is required, additional fees will be charged. The review result will be notified to you by email." 🤔. This ominous warning is probably not worth the $3 saved off of basic parts, so I'll see if there's a Basic and otherwise get an Extended. 

Extended things that ought to be basic: C170151, C60474, C106202 (maybe), C22367823, C368809, C39846661, C60490, C105872, C60491, C114760, C138033 (maybe), C25091, C36938886 (maybe).

You know, passives and stuff.

EDITS:

- Sourced an 0603 basic 22uF instead of 0402
- C170151 to C12530
- C60474 to C1525
- C106202 to C1549
- C368809 to C23733
- C60490 to C25744
- C105872 to C25905
- C60491 to C25741
- C114760 to C25752
- C138033 to C26083
- There exist zero good male USBC options !! I searched and searched and searched on jlcpcb.com/parts for Economic-supported male usbc options. And there wasn't a single good one. So I'm going to bite the bullet and just use usba. I have adapters. 99% of flash drives look this way anyways. Maybe this is why.

Got it down to $67.97. 

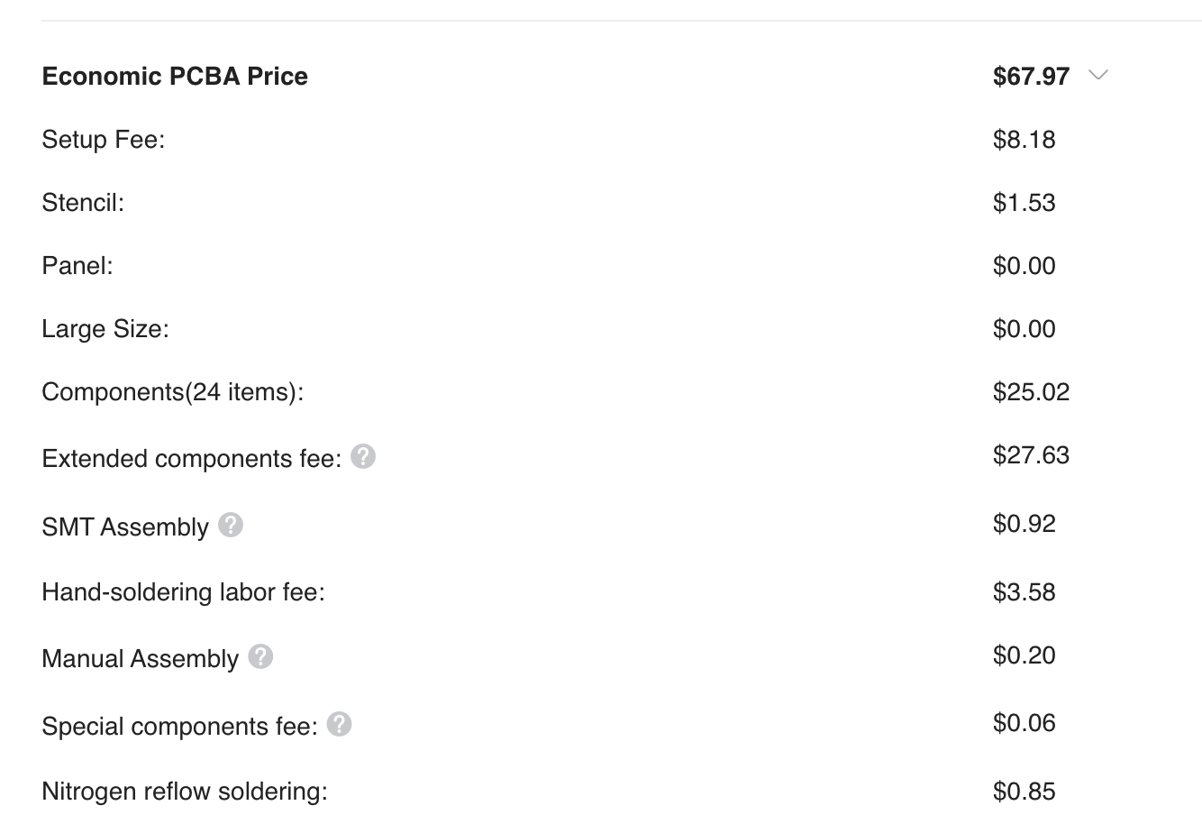
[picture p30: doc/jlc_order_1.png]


Which is honestly a reasonable price. And will be covered by the grant at this rate. So dubs!

Time spent: 1.5 hours

# August 2: Render and docs

Yeah! I tried to mess around with compositing a bit this time. I like the bright, well-lit background. I stacked subtle amounts of exposure, distortion, chromatic aberration, glare, and color correction on top of each other.

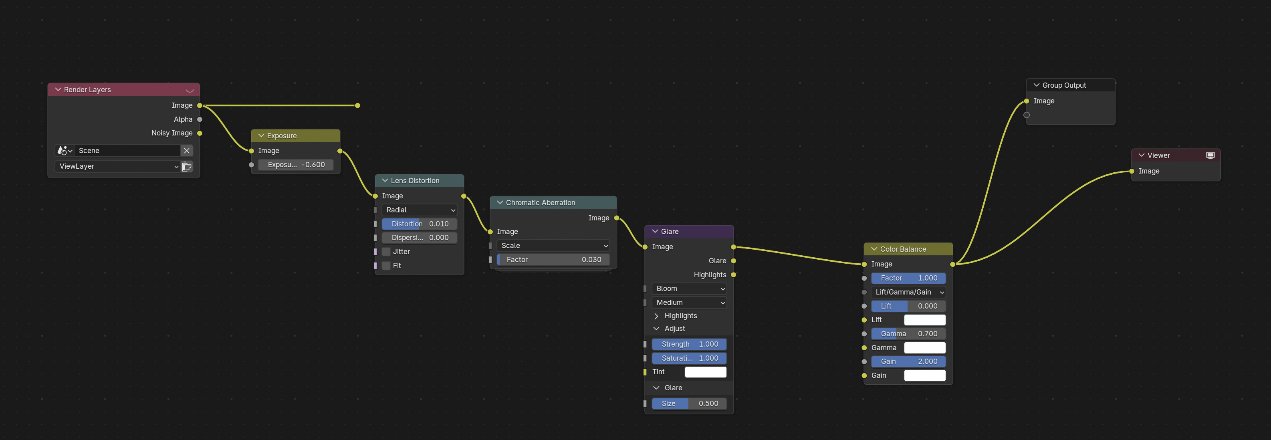
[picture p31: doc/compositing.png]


STEP export was so frustrating that I eventually just imported and re-exported from Onshape.



Time spent: 0.5 hours

# August 14: CAD and resubmit!

After review rejection, I revamped some stuff. Designed a case !. Should have some nice holes to slot into the m3 holes for secure mounting. Also I did internal fillet but external chamfer, and the chamfer looks so auraful.

I spent a long time figuring out what looks good. I got some ID inspo. Seems like the only "iconic" designer usb key is the LaCie Porsche Design USB key, and that's just a box 😭. SanDisk Extreme Pro is pretty good inspo too. But the rest is injection molded consumer electronics slop! I mostly did my own thing.

Oh also this happened offline, but I got an amazing price for an SD card!! $15 for 256GB. That's $0.059 per gb, cheaper than eMMC and SSD. Shoutout Gordon from LCSC for sourcing me this 闪迪高速游戏卡. Genuine sandisk, too. 

Then I re-checked that I met all the requirements. I also asked for some feedback / review in #electronics.

I also cleaned up the SD schematic

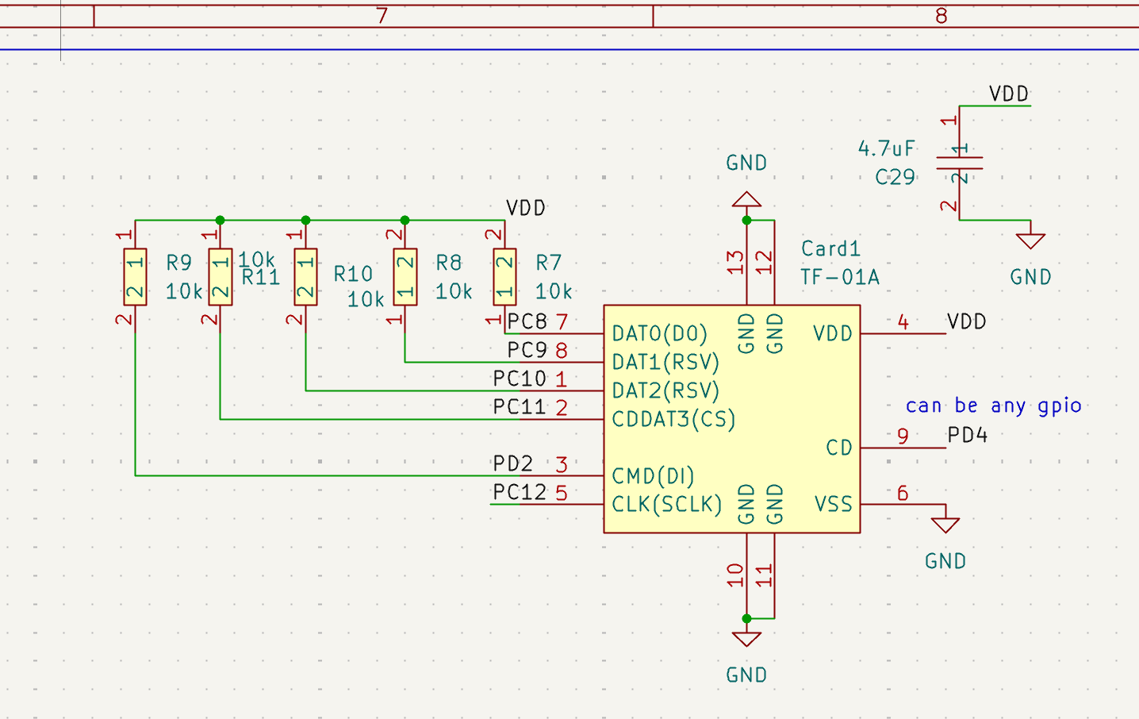
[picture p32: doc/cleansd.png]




Also it turns out you can flash over USB!!!! Maybe. I added it to the docs. This would be very convenient if so, but I'm keeping the uart and swd pins just in case. 

Time spent: 1.5 hours

# August 15: B.silkscreen

Just some tiny tweaks, I promise!

Had some fun with the silkscreen. Redid the swd labels to rotate, and added some test points.

Then for memes:

 - stm32h7 inside mimicing intel inside
 - sandisk gaming for the nerd cred + the "???" factor + Chinese product description for the visual texture
 - Considered adding: "not RoHS" or "designed by me in California" but eh idk if worth. 

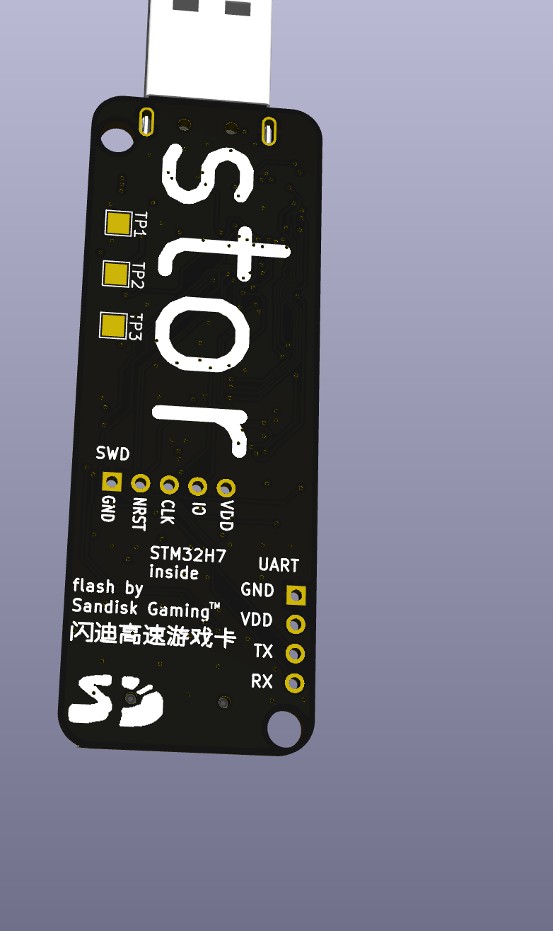
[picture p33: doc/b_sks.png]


I tried seeing if I wanted to re-source my buttons because they looked too tall in the 3d preview, but I realized that was just a bad 3d model. I re-sourced the part and the one that I found was the same one I already had 😭. This is like the "you search dementia and all the links are purple" meme. Anyways on the [page](https://www.lcsc.com/product-detail/C36938886.html) for it, it is actually good, and a normal height. So we're good.

Then I re-exported all the gerbers. Old prod in production_v1.

Time spent: 0.5 hours

# August 16: Auraful silkscreen

Discovered how to make cool labels! installed and played around with [kobee studio](https://github.com/mrcpuddington/kobeestudio), added some callouts and rearranged the silkscreen on F and B. 

It looks SO cool now!!

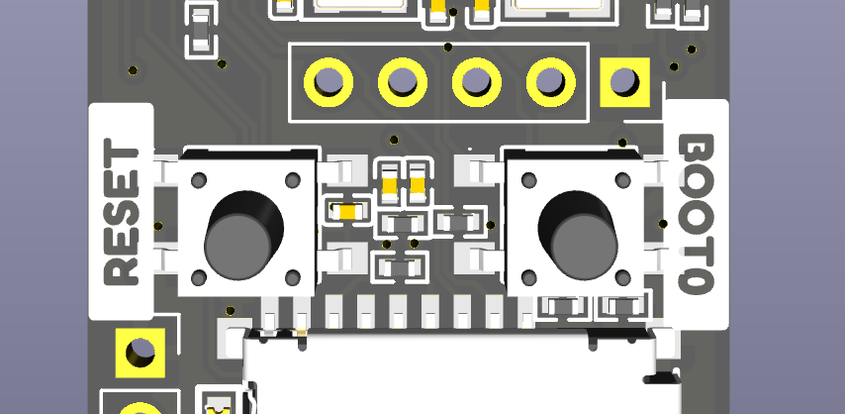
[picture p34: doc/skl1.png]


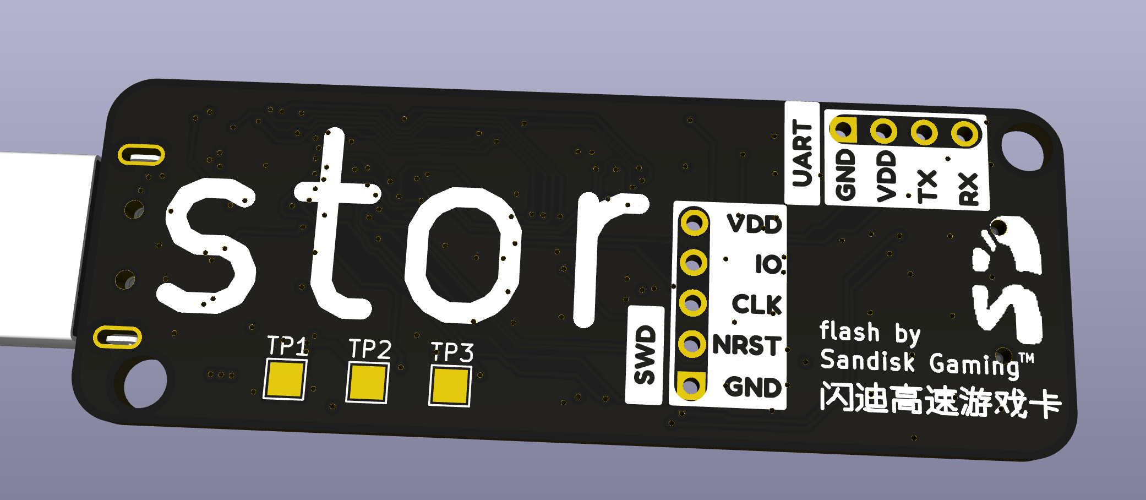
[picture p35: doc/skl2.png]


Time spent: 0.5 hours

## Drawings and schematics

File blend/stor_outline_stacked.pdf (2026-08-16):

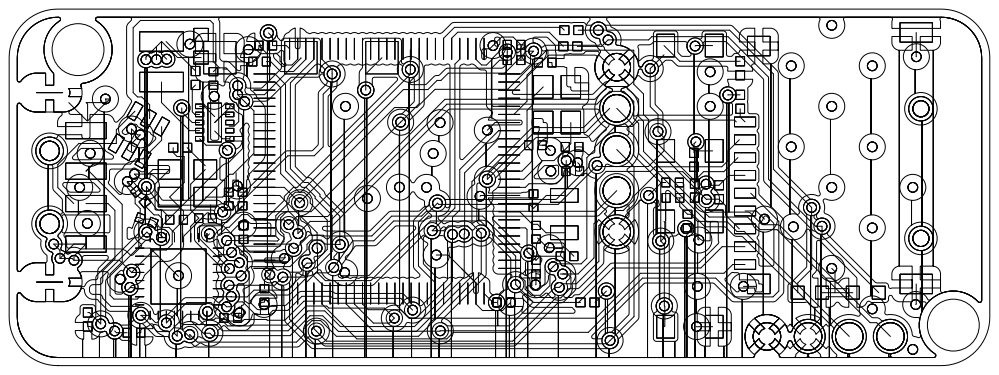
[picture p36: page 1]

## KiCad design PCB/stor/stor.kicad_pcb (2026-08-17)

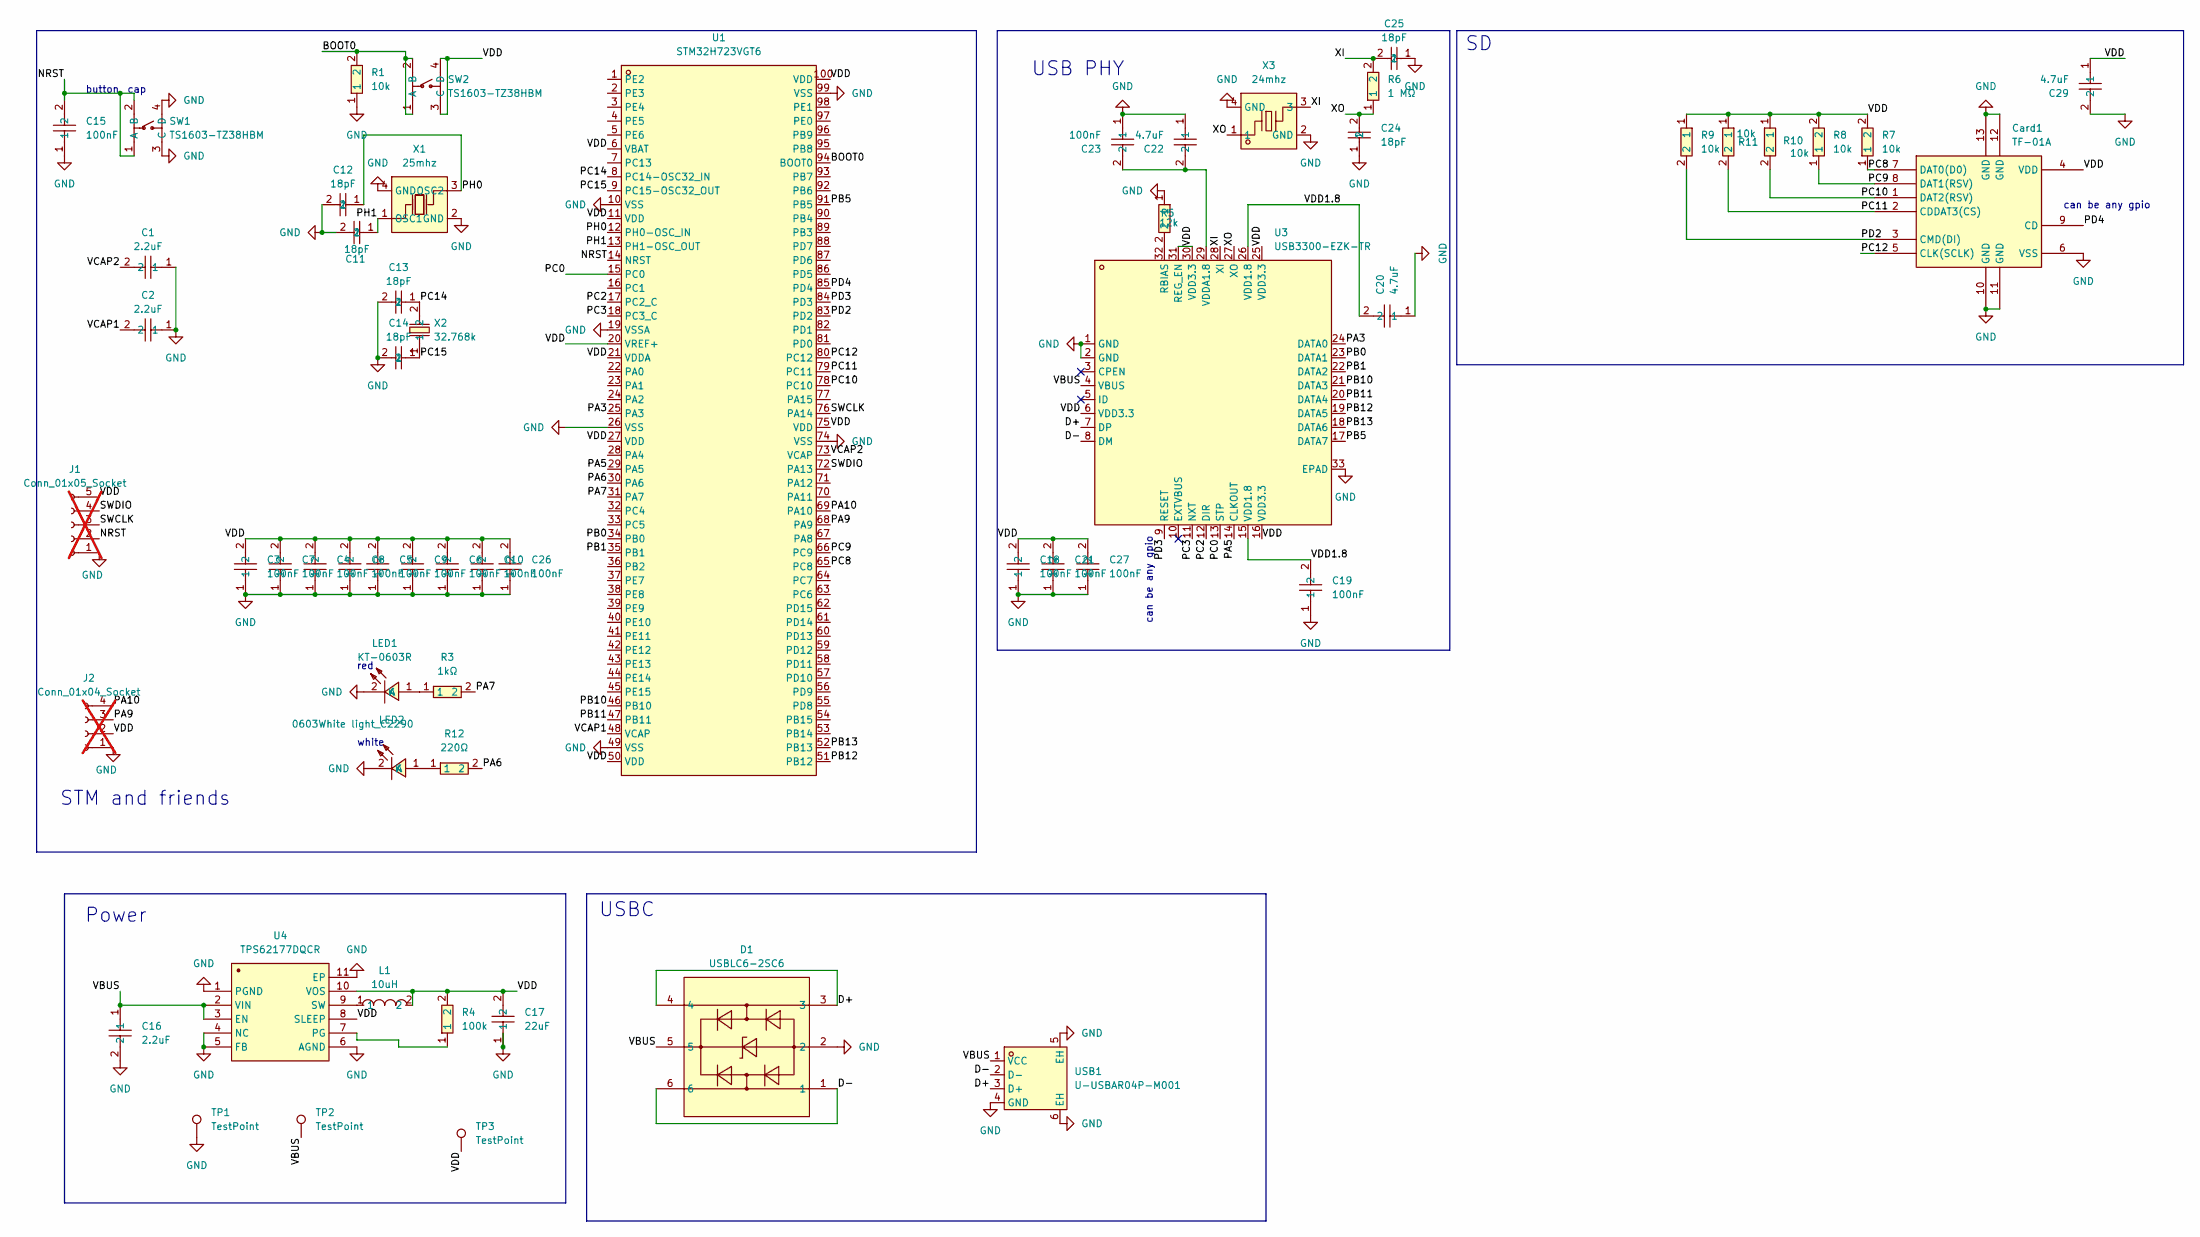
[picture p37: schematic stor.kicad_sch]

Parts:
C1, C2, C16: 2.2uF; C0402; MPN CL05A225MQ5NSNC; LCSC Part C12530
C3, C4, C5, C6, C7, C8, C9, C10, C15, C18, C19, C21, C23, C26, C27: 100nF; C0402; MPN CL05B104KO5NNNC; LCSC Part C1525
C11, C12, C13, C14, C24, C25: 18pF; C0402; MPN 0402CG180J500NT; LCSC Part C1549
C17: 22uF; C0603; MPN CL10A226MQ8NRNC; LCSC Part C59461
C20, C22, C29: 4.7uF; C0402; MPN CL05A475MP5NRNC; LCSC Part C23733
Card1: TF-01A; TF-SMD_TF-01A; MPN TF-01A; LCSC Part C91145
D1: USBLC6-2SC6; SOT-23-6_L2.9-W1.6-P0.95-LS2.8-BL; MPN USBLC6-2SC6; LCSC Part C7519
J1: Conn_01x05_Socket; PinSocket_1x05_P2.54mm_Vertical; not fitted
J2: Conn_01x04_Socket; PinSocket_1x04_P2.54mm_Vertical; not fitted
L1: 10uH; IND-SMD_L3.2-W2.5_CKST322512-2.2UH; MPN XRTC322512S100MBCA; LCSC Part C39846661
LED1: KT-0603R; LED-SMD_L1.6-W0.8-R-RD; MPN KT-0603R; LCSC Part C2286
LED2: 0603White light_C2290; LED0603-R-RD_WHITE; MPN KT-0603W; LCSC Part C2290
R1, R7, R8, R9, R10, R11: 10k; R0402; MPN 0402WGF1002TCE; LCSC Part C25744
R3: 1kΩ; R0402; MPN 0402WGF1001TCE; LCSC Part C11702
R4: 100k; R0402; MPN 0402WGF1003TCE; LCSC Part C25741
R5: 12k; R0402; MPN 0402WGF1202TCE; LCSC Part C25752
R6: 1 MΩ; R0402; MPN 0402WGF1004TCE; LCSC Part C26083
R12: 220Ω; R0402; MPN 0402WGF2200TCE; LCSC Part C25091
SW1, SW2: TS1603-TZ38HBM; SW-SMD_4P-L4.5-W4.5-P3.00-LS6.8; MPN TS1603-TZ38HBM; LCSC Part C36938886
TP1, TP2, TP3: TestPoint; TestPoint_Pad_2.0x2.0mm
U1: STM32H723VGT6; LQFP-100_L14.0-W14.0-P0.50-LS16.0-BL; MPN STM32H723VGT6; LCSC Part C730142
U3: USB3300-EZK-TR; QFN-32_L5.0-W5.0-P0.50-BL-EP3.4; MPN USB3300-EZK-TR; LCSC Part C108383
U4: TPS62177DQCR; WSON-10_L3.0-W2.0-P0.50-BL-EP; MPN TPS62177DQCR; LCSC Part C91241
USB1: U-USBAR04P-M001; USB-SMD_KH-USB-AM-4P-CB; MPN U-USBAR04P-M003; LCSC Part C386752
X1: 25mhz; CRYSTAL-SMD_4P-L3.2-W2.5-BL; MPN X322525MOB4SI; LCSC Part C9006
X2: 32.768k; OSC-SMD_L3.2-W1.5; MPN SC-32S32.768kHz20PPM12.5pF; LCSC Part C97606
X3: 24mhz; CRYSTAL-SMD_4P-L3.2-W2.5-BL; MPN SX32Y024000BC1T001; LCSC Part C7420736

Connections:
/BOOT0: R1.2, SW2.1 (A), SW2.2 (B), U1.94 (BOOT0)
/D+: D1.3, D1.4, U3.7 (DP), USB1.3 (D+)
/D-: D1.1, D1.6, U3.8 (DM), USB1.2 (D-)
/NRST: C15.2, J1.2, SW1.1 (A), SW1.2 (B), U1.14 (NRST)
/PA3: U1.25 (PA3), U3.24 (DATA0)
/PA5: U1.29 (PA5), U3.14 (CLKOUT)
/PA6: R12.2, U1.30 (PA6)
/PA7: R3.2, U1.31 (PA7)
/PA9: J2.3, U1.68 (PA9)
/PA10: J2.4, U1.69 (PA10)
/PB0: U1.34 (PB0), U3.23 (DATA1)
/PB1: U1.35 (PB1), U3.22 (DATA2)
/PB5: U1.91 (PB5), U3.17 (DATA7)
/PB10: U1.46 (PB10), U3.21 (DATA3)
/PB11: U1.47 (PB11), U3.20 (DATA4)
/PB12: U1.51 (PB12), U3.19 (DATA5)
/PB13: U1.52 (PB13), U3.18 (DATA6)
/PC0: U1.15 (PC0), U3.13 (STP)
/PC2: U1.17 (PC2_C), U3.12 (DIR)
/PC3: U1.18 (PC3_C), U3.11 (NXT)
/PC8: Card1.7 (DAT0(D0)), R7.1, U1.65 (PC8)
/PC9: Card1.8 (DAT1(RSV)), R8.1, U1.66 (PC9)
/PC10: Card1.1 (DAT2(RSV)), R10.2, U1.78 (PC10)
/PC11: Card1.2 (CDDAT3(CS)), R11.2, U1.79 (PC11)
/PC12: Card1.5 (CLK(SCLK)), U1.80 (PC12)
/PC14: C13.1, U1.8 (PC14-OSC32_IN), X2.2
/PC15: C14.1, U1.9 (PC15-OSC32_OUT), X2.1
/PD2: Card1.3 (CMD(DI)), R9.2, U1.83 (PD2)
/PD3: U1.84 (PD3), U3.9 (RESET)
/PD4: Card1.9 (CD), U1.85 (PD4)
/PH0: C12.1, U1.12 (PH0-OSC_IN), X1.3 (OSC2)
/PH1: C11.1, U1.13 (PH1-OSC_OUT), X1.1 (OSC1)
/SWCLK: J1.3, U1.76 (PA14)
/SWDIO: J1.4, U1.72 (PA13)
/VBUS: C16.1, D1.5, TP2.1 (1_1), U3.4 (VBUS), U4.2 (VIN), U4.3 (EN), USB1.1 (VCC)
/VCAP1: C2.2, U1.48 (VCAP)
/VCAP2: C1.2, U1.73 (VCAP)
/VDD: C3.2, C4.2, C5.2, C6.2, C7.2, C8.2, C9.2, C10.2, C17.2, C18.2, C21.2, C26.2, C27.2, C29.1, Card1.4 (VDD), J1.5, J2.2, L1.2, R4.2, R7.2, R8.2, R9.1, R10.1, R11.1, SW2.3 (C), SW2.4 (D), TP3.1 (1_1), U1.6 (VBAT), U1.11 (VDD), U1.20 (VREF+), U1.21 (VDDA), U1.27 (VDD), U1.50 (VDD), U1.75 (VDD), U1.100 (VDD), U3.6 (VDD3.3), U3.16 (VDD3.3), U3.25 (VDD3.3), U3.30 (VDD3.3), U3.31 (REG_EN), U4.8 (SLEEP), U4.10 (VOS)
/VDD1.8: C19.2, C20.2, U3.15 (VDD1.8), U3.26 (VDD1.8)
/XI: C25.2, R6.2, U3.28 (XI), X3.3
/XO: C24.2, R6.1, U3.27 (XO), X3.1
GND: C1.1, C2.1, C3.1, C4.1, C5.1, C6.1, C7.1, C8.1, C9.1, C10.1, C11.2, C12.2, C13.2, C14.2, C15.1, C16.2, C17.1, C18.1, C19.1, C20.1, C21.1, C22.1, C23.1, C24.1, C25.1, C26.1, C27.1, C29.2, Card1.6 (VSS), Card1.10 (GND), Card1.11 (GND), Card1.12 (GND), Card1.13 (GND), D1.2, J1.1, J2.1, LED1.2 (K), LED2.2 (K), R1.1, R5.1, SW1.3 (C), SW1.4 (D), TP1.1 (1_1), U1.10 (VSS), U1.19 (VSSA), U1.26 (VSS), U1.49 (VSS), U1.74 (VSS), U1.99 (VSS), U3.1 (GND), U3.2 (GND), U3.33 (EPAD), U4.1 (PGND), U4.4 (NC), U4.5 (FB), U4.6 (AGND), U4.11 (EP), USB1.4 (GND), USB1.5 (EH), USB1.6 (EH), X1.2 (GND), X1.4 (GND), X3.2 (GND), X3.4 (GND)
unnamed: LED1.1 (A), R3.1
unnamed: LED2.1 (A), R12.1
unnamed: R5.2, U3.32 (RBIAS)
unnamed: C22.2, C23.2, U3.29 (VDDA1.8)
unnamed: R4.1, U4.7 (PG)
unnamed: L1.1, U4.9 (SW)

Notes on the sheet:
can be any gpio
USBC
white
red
STM and friends
can be any gpio
USB PHY
Power
button, cap

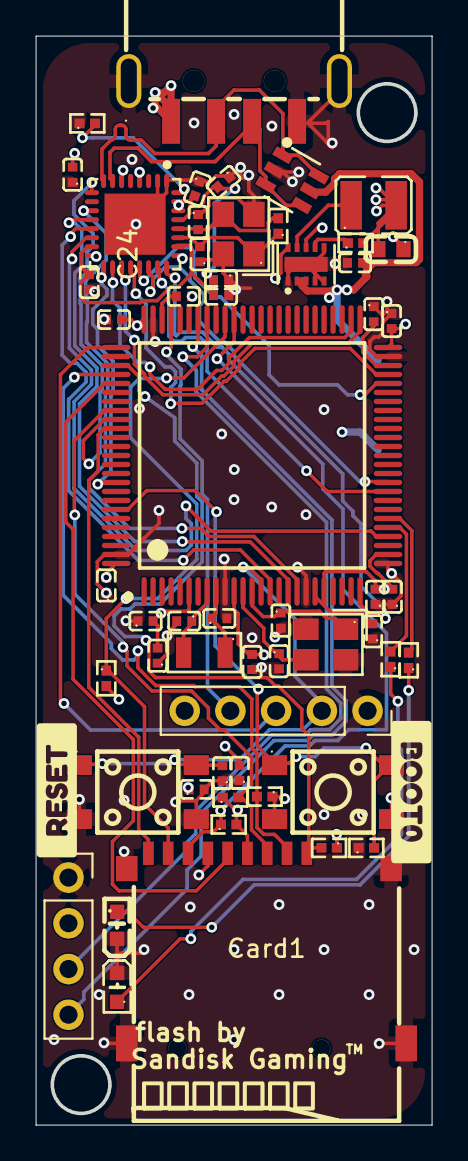
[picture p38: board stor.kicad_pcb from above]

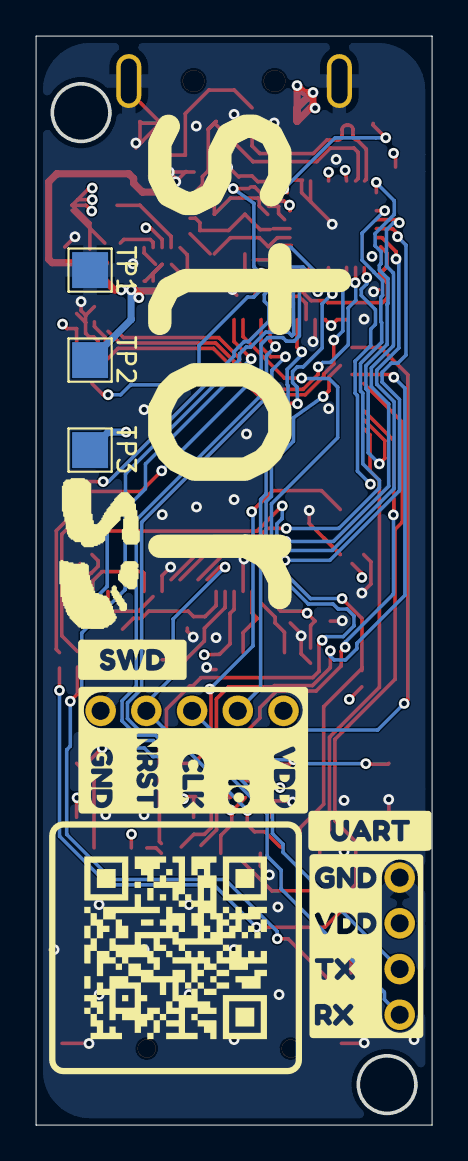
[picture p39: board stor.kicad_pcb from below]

Board: 4 copper layers, 22.0 x 60.5 mm, 65 parts (8 on the bottom side), 48 nets.

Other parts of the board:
kobee-studio-6A81F80C: Kobee Studio; kobee-studio-6A81F4CE
kobee-studio-6A8143AA: Kobee Studio; kobee-studio-6A8143AA
kobee-studio-6A8143BF: Kobee Studio; kobee-studio-6A8143BF
kobee-studio-6A8144FF: Kobee Studio; kobee-studio-6A8144FF
kobee-studio-6A81454B: Kobee Studio; kobee-studio-6A81454B
kobee-studio-6A814325: Kobee Studio; kobee-studio-6A814325
kobee-studio-6A814354: Kobee Studio; kobee-studio-6A814354

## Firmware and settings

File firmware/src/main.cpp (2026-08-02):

#include "board.hpp"
#include "clock.hpp"
#include "logging.hpp"
#include "sd.hpp"
#include "stm32h7xx_hal.h"
#include "tusb.h"

int main() {
  HAL_Init();
  clock::init();
  board::init();
  logging::init();
  logging::printf("stor: boot, SYSCLK %lu Hz", static_cast<unsigned long>(SystemCoreClock));

  board::reset_phy();
  if (!board::phy_clock_alive()) {
    logging::fatal("no ULPI clock on PA5; check U3 reset (PD3) and the 24 MHz X3");
  }

  board::enable_usb_clocks();
  tusb_init();
  sd::poll_presence();

  uint32_t last_poll = HAL_GetTick();
  while (true) {
    tud_task();
    if (HAL_GetTick() - last_poll >= 100) { // 100 ms
      last_poll = HAL_GetTick();
      sd::poll_presence();
    }
  }
}

extern "C" {

void SysTick_Handler() { HAL_IncTick(); }

void OTG_HS_IRQHandler() { tud_int_handler(0); }

}

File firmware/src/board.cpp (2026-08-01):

#include "board.hpp"

#include "stm32h7xx_hal.h"

namespace {


GPIO_TypeDef* const kLedActivityPort = GPIOA;
constexpr uint16_t kLedActivityPin = GPIO_PIN_6;
GPIO_TypeDef* const kLedErrorPort = GPIOA;
constexpr uint16_t kLedErrorPin = GPIO_PIN_7;

constexpr uint16_t kPhyResetPin = GPIO_PIN_3;   // PD3, active high
constexpr uint16_t kCardDetectPin = GPIO_PIN_4; // PD4
constexpr uint16_t kUlpiClockPin = GPIO_PIN_5;  // PA5

struct PinCfg {
  GPIO_TypeDef* port;
  uint16_t pin;
  uint32_t mode;
  uint32_t pull;
  uint32_t alternate;
};

const PinCfg kPins[] = {
    // ULPI: CK, D0-D7, STP, DIR, NXT
    {GPIOA, GPIO_PIN_5, GPIO_MODE_AF_PP, GPIO_NOPULL, GPIO_AF10_OTG1_HS},
    {GPIOA, GPIO_PIN_3, GPIO_MODE_AF_PP, GPIO_NOPULL, GPIO_AF10_OTG1_HS},
    {GPIOB, GPIO_PIN_0, GPIO_MODE_AF_PP, GPIO_NOPULL, GPIO_AF10_OTG1_HS},
    {GPIOB, GPIO_PIN_1, GPIO_MODE_AF_PP, GPIO_NOPULL, GPIO_AF10_OTG1_HS},
    {GPIOB, GPIO_PIN_10, GPIO_MODE_AF_PP, GPIO_NOPULL, GPIO_AF10_OTG1_HS},
    {GPIOB, GPIO_PIN_11, GPIO_MODE_AF_PP, GPIO_NOPULL, GPIO_AF10_OTG1_HS},
    {GPIOB, GPIO_PIN_12, GPIO_MODE_AF_PP, GPIO_NOPULL, GPIO_AF10_OTG1_HS},
    {GPIOB, GPIO_PIN_13, GPIO_MODE_AF_PP, GPIO_NOPULL, GPIO_AF10_OTG1_HS},
    {GPIOB, GPIO_PIN_5, GPIO_MODE_AF_PP, GPIO_NOPULL, GPIO_AF10_OTG1_HS},
    {GPIOC, GPIO_PIN_0, GPIO_MODE_AF_PP, GPIO_NOPULL, GPIO_AF10_OTG1_HS},
    {GPIOC, GPIO_PIN_2, GPIO_MODE_AF_PP, GPIO_NOPULL, GPIO_AF10_OTG1_HS},
    {GPIOC, GPIO_PIN_3, GPIO_MODE_AF_PP, GPIO_NOPULL, GPIO_AF10_OTG1_HS},
    // SDMMC1: D0-D3, CK, CMD
    {GPIOC, GPIO_PIN_8, GPIO_MODE_AF_PP, GPIO_NOPULL, GPIO_AF12_SDMMC1},
    {GPIOC, GPIO_PIN_9, GPIO_MODE_AF_PP, GPIO_NOPULL, GPIO_AF12_SDMMC1},
    {GPIOC, GPIO_PIN_10, GPIO_MODE_AF_PP, GPIO_NOPULL, GPIO_AF12_SDMMC1},
    {GPIOC, GPIO_PIN_11, GPIO_MODE_AF_PP, GPIO_NOPULL, GPIO_AF12_SDMMC1},
    {GPIOC, GPIO_PIN_12, GPIO_MODE_AF_PP, GPIO_NOPULL, GPIO_AF12_SDMMC1},
    {GPIOD, GPIO_PIN_2, GPIO_MODE_AF_PP, GPIO_NOPULL, GPIO_AF12_SDMMC1},
    // USART1 console
    {GPIOA, GPIO_PIN_9, GPIO_MODE_AF_PP, GPIO_NOPULL, GPIO_AF7_USART1},
    {GPIOA, GPIO_PIN_10, GPIO_MODE_AF_PP, GPIO_NOPULL, GPIO_AF7_USART1},
    // PHY reset, driven low (released) once configured
    {GPIOD, kPhyResetPin, GPIO_MODE_OUTPUT_PP, GPIO_NOPULL, 0},
    // Card detect
    {GPIOD, kCardDetectPin, GPIO_MODE_INPUT, GPIO_PULLUP, 0},
    // LEDs: PA6 white (activity), PA7 red (error)
    {GPIOA, GPIO_PIN_6, GPIO_MODE_OUTPUT_PP, GPIO_NOPULL, 0},
    {GPIOA, GPIO_PIN_7, GPIO_MODE_OUTPUT_PP, GPIO_NOPULL, 0},
};

void apply(const PinCfg& cfg) {
  GPIO_InitTypeDef init{};
  init.Pin = cfg.pin;
  init.Mode = cfg.mode;
  init.Pull = cfg.pull;
  init.Speed = GPIO_SPEED_FREQ_VERY_HIGH;
  init.Alternate = cfg.alternate;
  HAL_GPIO_Init(cfg.port, &init);
}

}

namespace board {

void init() {
  __HAL_RCC_GPIOA_CLK_ENABLE();
  __HAL_RCC_GPIOB_CLK_ENABLE();
  __HAL_RCC_GPIOC_CLK_ENABLE();
  __HAL_RCC_GPIOD_CLK_ENABLE();
  __HAL_RCC_SYSCFG_CLK_ENABLE();
  __HAL_RCC_USART1_CLK_ENABLE();

  HAL_SYSCFG_AnalogSwitchConfig(SYSCFG_SWITCH_PC2, SYSCFG_SWITCH_PC2_CLOSE);
  HAL_SYSCFG_AnalogSwitchConfig(SYSCFG_SWITCH_PC3, SYSCFG_SWITCH_PC3_CLOSE);

  for (const PinCfg& cfg : kPins) {
    apply(cfg);
  }
}

void reset_phy() {
  HAL_GPIO_WritePin(GPIOD, kPhyResetPin, GPIO_PIN_SET);
  HAL_Delay(1);
  HAL_GPIO_WritePin(GPIOD, kPhyResetPin, GPIO_PIN_RESET);
  HAL_Delay(10);
}

bool phy_clock_alive() {
  GPIO_InitTypeDef probe{};
  probe.Pin = kUlpiClockPin;
  probe.Mode = GPIO_MODE_INPUT;
  probe.Pull = GPIO_NOPULL;
  probe.Speed = GPIO_SPEED_FREQ_VERY_HIGH;
  HAL_GPIO_Init(GPIOA, &probe);

  bool saw_high = false;
  bool saw_low = false;
  for (uint32_t i = 0; i < 100000 && !(saw_high && saw_low); ++i) {
    if (HAL_GPIO_ReadPin(GPIOA, kUlpiClockPin) == GPIO_PIN_SET) {
      saw_high = true;
    } else {
      saw_low = true;
    }
  }

  apply(kPins[0]);
  return saw_high && saw_low;
}

void enable_usb_clocks() {
  __HAL_RCC_USB1_OTG_HS_CLK_ENABLE();
  __HAL_RCC_USB1_OTG_HS_ULPI_CLK_ENABLE();
}

bool card_present() {
  const bool low = HAL_GPIO_ReadPin(GPIOD, kCardDetectPin) == GPIO_PIN_RESET;
  return kCardDetectActiveLow ? low : !low;
}

void led(Led which, bool on) {
  GPIO_TypeDef* port = (which == Led::Activity) ? kLedActivityPort : kLedErrorPort;
  const uint16_t pin = (which == Led::Activity) ? kLedActivityPin : kLedErrorPin;
  HAL_GPIO_WritePin(port, pin, on ? GPIO_PIN_SET : GPIO_PIN_RESET);
}

}

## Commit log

2026-07-29 all sketched except power section
    [stor.kicad_sch]
2026-07-29 gnda, vss
    [stor.kicad_sch]
2026-07-29 buck sourced
    [stor.kicad_sch]
2026-07-29 stm and friends complete
    [stor.kicad_sch]
2026-07-29 pmic done
    [stor.kicad_sch]
2026-07-29 fill out usb phy
    [stor.kicad_sch]
2026-07-29 usb phy
    [stor.kicad_sch]
2026-07-29 usb phy p much done and dusted
    [stor.kicad_sch]
2026-07-29 esd protection
    [stor.kicad_sch]
2026-07-29 schematic is, as far as I know, done!
    [stor.kicad_pcb, stor.kicad_sch]
2026-07-29 placement for all but the silly caps
    [stor.kicad_pcb, stor.kicad_sch]
2026-07-29 all placed
    [stor.kicad_pcb]
2026-07-29 some routing
    [stor.kicad_pcb]
2026-07-29 crazy refactor to accomodate diffpair
    [stor.kicad_pcb]
2026-07-30 soo much routing
    [stor.kicad_pcb, stor.kicad_sch]
2026-07-30 new usb and uh finish routing!
    [stor.kicad_pcb, stor.kicad_sch]
2026-07-30 smal changes
    [stor.kicad_pcb]
2026-07-30 fussed with the routing I guess
    [stor.kicad_pcb]
2026-07-31 mince the PCB
    [stor.kicad_pcb]
2026-07-31 docs up to placement
    [stor.kicad_pcb]
2026-07-31 mounting holes!!
    [stor.kicad_pcb]
2026-08-01 Revert "um"
    This reverts commit f612a820e098ebaa8285b4f3f2874b1805a4782c.
    [stor.kicad_pcb, stor.kicad_sch]
2026-08-01 Reapply "um"
    This reverts commit 07b64e62ca9c6bf6512e2ad29080b55d79604863.
    [stor.kicad_pcb, stor.kicad_sch]
2026-08-01 no uhs
    [stor.kicad_pcb]
2026-08-01 firmware and LEDs lol
    [stor.kicad_pcb, stor.kicad_sch]
2026-08-02 new usb
    [stor.kicad_pcb, stor.kicad_sch]
2026-08-02 bom opt!!
    [diff.txt, stor.kicad_pcb, stor.kicad_sch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]
2026-08-15 cadded the case!
    [stor_assembly.step, stor_case.step]
2026-08-15 sch cleanup
    [stor.kicad_pcb, stor.kicad_sch]
2026-08-15 rbias placement
    [stor.kicad_pcb]
2026-08-15 production 2!
    [diff.txt, stor.kicad_pcb, stor.kicad_sch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]
